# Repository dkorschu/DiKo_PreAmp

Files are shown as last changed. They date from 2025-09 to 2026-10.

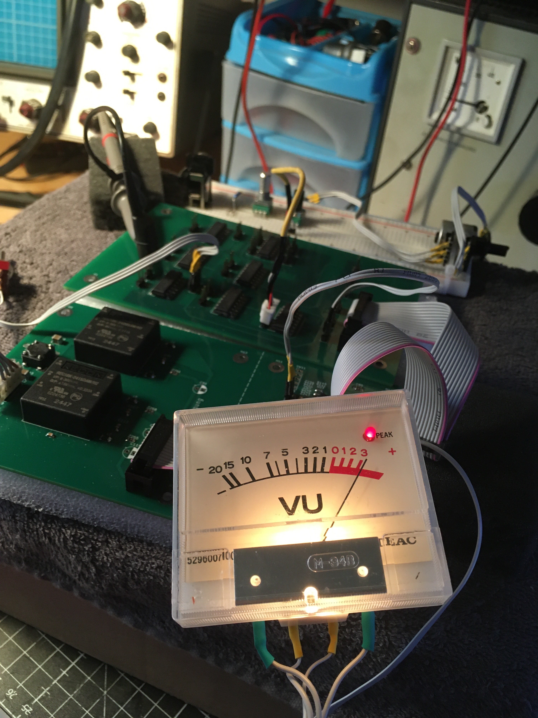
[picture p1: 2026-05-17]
Version 2/Pictures/Peak_Test.jpg

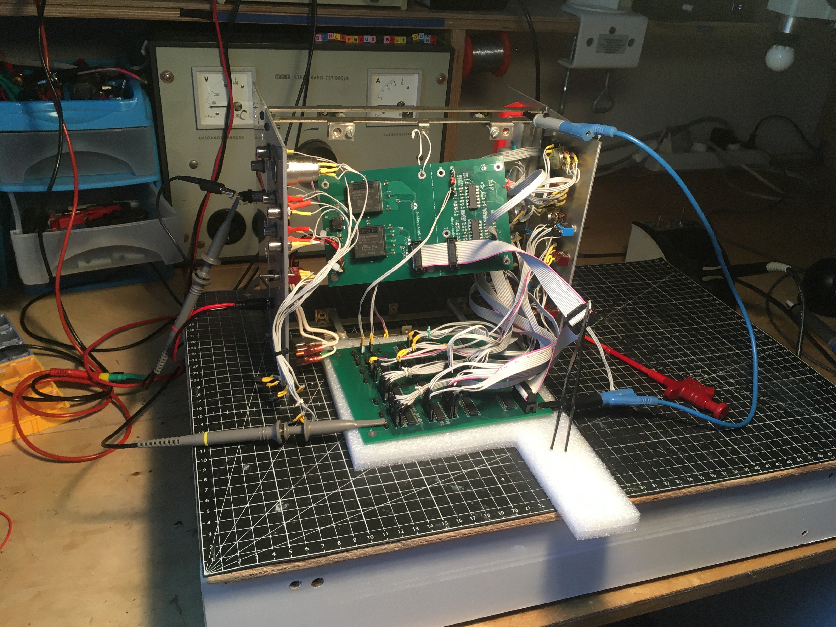
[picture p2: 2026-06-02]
Version 2/Pictures/Versuchsaufbau.jpg

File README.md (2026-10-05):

# $\text{-DIKO-}\sqrt{\text{REGGAE}}\text{-PREAMP-}$

[English version below](#english-version)

Dieses Repository zeigt die Entwicklung des DIKO ELEKTROTECHNIK Vorverstärkers, vom ersten Prototyp bis zum aktuellen Stand.

## Ordnerstruktur

- Blockschaltbilder
- Ältere Versionen
- KiCad Dateien
- Bilder
- Datenblätter
- 3D Druck

## Version 1

Version 1 entstand im Rahmen meiner Bachelorarbeit. Schaltpläne und Fertigungsdateien der Platinen wurden mit Altium Designer erstellt. Das Besondere an dieser Version: Die analoge Frequenzweiche lässt sich über Digitalpotentiometer einstellen.

**Hinweis: Version 1 ist fehlerhaft!**

## Version 2

Version 2 baut auf den Erkenntnissen aus Version 1 auf und bringt komplett neue Platinen mit. Die Digitalpotentiometer sind entfallen, da der Vorverstärker einfacher werden und der Fokus zunächst auf der analogen Schaltungstechnik liegen sollte. Zur Berechnung der Frequenzweiche wurden außerdem Jupyter Notebooks eingesetzt, die sehr gute Ergebnisse geliefert haben.

Bei den bisherigen Tests wurden schaltungstechnisch keine Fehler gefunden. Trotzdem gibt es zwei Schwachstellen:

- Das Platinenlayout ist nicht zufriedenstellend.
- Der Mikrofonvorverstärker verstärkt das Signal nicht ausreichend.

Aus diesen Gründen wird nun an Version 3 gearbeitet.

## Version 3

Version 3 teilt den Vorverstärker in einzelne Komponenten auf, die sich miteinander verbinden lassen.

2026_10_05 Den Anfang macht die Frequenzweiche, die sich auch eigenständig mit einem externen Mischpult nutzen lässt.

---

# English Version

This repository documents the development of the DIKO ELEKTROTECHNIK preamplifier, from the first prototype to the current state.

## Folder Structure

- Blockschaltbilder (block diagrams)
- Ältere Versionen (older versions)
- KiCad Dateien (KiCad files)
- Bilder (images)
- Datenblätter (datasheets)
- 3D Druck (3D printing)

## Version 1
Version 1 was developed as part of my bachelor's thesis. The schematics and PCB manufacturing files were created with Altium Designer. What makes this version special: the analog crossover can be adjusted using digital potentiometers.

**Note: Version 1 is faulty!**

## Version 2

Version 2 builds on the findings from Version 1 and comes with completely new PCBs. The digital potentiometers were removed to make the preamp simpler and to focus on the analog circuitry first. In addition, Jupyter Notebooks were used to calculate the crossover, with very good results.

So far, testing has not revealed any circuit errors. However, there are two weak points:

- The PCB layout is not satisfactory.
- The microphone preamp does not amplify the signal sufficiently.

For these reasons, work is now underway on Version 3.

## Version 3

Version 3 splits the preamp into individual components that can be connected to each other.

2026_10_05 The first step is the crossover, which can also be used on its own with an external mixing console.

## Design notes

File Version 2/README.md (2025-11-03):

# DiKo\_PreAmp

This repository contains all resources related to the design, development and documentation of an audio preamplifier that was created as part of a bachelor’s thesis. The preamplifier includes a crossover network whose transmission characteristics can be adjusted using digital potentiometers.

## Repository Structure

* **3D\_Print/**  

&nbsp;	Contains 3D print files for the PCB mounting bracket.

* **Altium/**  

&nbsp;	Altium Designer project of the preamplifier, including schematics and Gerber files.  
	Note: The current design contains electrical errors. These will be documented and fixed in an upcoming update.

* **Bachelor\_Thesis/**  

&nbsp;	Includes the bachelor’s thesis in which the preamplifier was developed.

* **Blockdiagram/**  

&nbsp;	Contains the block diagram of the preamplifier.

* **Pictures/**  

&nbsp;	Photos of the preamplifier prototype.

* **Software/**  

&nbsp;	Source code for both the microcontroller firmware and the desktop application used to control the digital potentiometers.
	The microcontroller was programmed using the Arduino IDE and the desktop application was developed in C# with Microsoft Visual Studio.

* **KiCad/**

&nbsp;	KiCad project of the preamplifier, including schematics and Gerber files.  

&nbsp;	Note: The current data set is incomplete and will be completed in an upcoming update.

* **Datasheed/**

	Contains data sheets and related reference information for the project components.

## Status

* Initial release of design files and documentation.
* Known circuit errors in the **Altium/** project (to be listed in detail soon).

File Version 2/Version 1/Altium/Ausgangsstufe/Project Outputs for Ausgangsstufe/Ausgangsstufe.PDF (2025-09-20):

Comment | Description | Designator | Footprint | LibRef | Quantity
OPA4134UA | SoundPlus(TM) High Performance Audio Operational Amplifier, 5 to 36 V, -55 to 125 degC, 14-pin SOIC (D14), Green (RoHS & no Sb/Br) | U22, U23, U24, U25, U26, U27, U28, U29, U30 | DIP14 IC Socket | SOIC OPA4134UA | 9
Schalter Buchsenleiste | Toggle Switch SPDT Through Hole | S1, S2, S3, S4 | Connector x3 | Schalter Buchsenleiste | 4
18k | 0805 Widerstand | R103 | 0805 | 0805 Widerstand | 1
100k | 0805 Widerstand | R93 | 0805 | 0805 Widerstand | 1
1k8 | 0805 Widerstand | R92, R97 | 0805 | 0805 Widerstand | 2
10k lin | 4mm Square Trimpot(R) Trimming Potentiometer, 5 KOhm, +/- 20%, 0.25 W, -55 to 125 degC, 3-Pin SMD, RoHS, Tape and Reel | R91 | SMD Trimmer 3314G | SMD Trimmer 3314G | 1
200k | 0805 Widerstand | R88, R99, R106 | 0805 | 0805 Widerstand | 3
50k lin | 4mm Square Trimpot(R) Trimming Potentiometer, 5 KOhm, +/- 20%, 0.25 W, -55 to 125 degC, 3-Pin SMD, RoHS, Tape and Reel | R82 | SMD Trimmer 3314G | SMD Trimmer 3314G | 1
3k9 | 0805 Widerstand | R79 | 0805 | 0805 Widerstand | 1
220 | 0805 Widerstand | R75 | 0805 | 0805 Widerstand | 1
1k | 0805 Widerstand | R49, R65, R81 | 0805 | 0805 Widerstand | 3
470R | 0805 Widerstand | R45, R47, R48, R50, R51, R59, R77, R87, R98 | 0805 | 0805 Widerstand | 9
22k log | Potentiometer | R44, R58, R73 | Connector x3 | Potentiometer Buchsenleiste | 3
4k7 | 0805 Widerstand | R41, R57, R67, R72, R76 | 0805 | 0805 Widerstand | 5
47k log/str | Potentiometer | R28, R29 | Connector x3 | Potentiometer Buchsenleiste | 2
5k | 0805 Widerstand | R24, R31 | 0805 | 0805 Widerstand | 2
10k | 0805 Widerstand | R17, R18, R19, R20, R21, R23, R40, R56, R66, R69, R70, R71, R74, R78, R84, R85, R86, R95, R96, R105 | 0805 | 0805 Widerstand | 20
47k lin | Potentiometer | R15, R16, R42, R43 | Connector x3 | Potentiometer Buchsenleiste | 4
220k | 0805 Widerstand | R13, R14, R30, R38, R39, R46, R52, R53, R54, R55, R60, R61, R62, R63, R64, R68, R80, R83, R89, R90, R94, R100, R101, R102, R104, R107 | 0805 | 0805 Widerstand | 26
6.8k | 0805 Widerstand | R7, R8, R10, R11, R32, R33, R34, R36 | 0805 | 0805 Widerstand | 8
470k log/str | Potentiometer | R5, R6 | Connector x3 | Potentiometer Buchsenleiste | 2
22k log/str | Potentiometer | R2, R3, R26, R27 | Connector x3 | Potentiometer Buchsenleiste | 4
22k | 0805 Widerstand | R1, R4, R9, R12, R22, R25, R35, R37 | 0805 | 0805 Widerstand | 8
BC817-40,215 | TRANS NPN 45V 0.5A SOT23 | Q2 | SOT23 Transistor | SOT23 BC817NPN | 1
BC807-40LT1G | General Purpose Transistor, PNP Silicon, 3-Pin SOT-23, Pb-Free, Tape and Reel | Q1 | SOT23 Transistor | SOT23 BC807 PNP | 1
VU Meter | CONN RCPT 4POS 0.1 GOLD PCB | J10 | Connector x4 | Connector x4 | 1
Connector x14 | 14 Position Header Connector Through Hole | J9 | Connector x14 | Connector x14 | 1
Connector x2 | Connector Header Through Hole 2 position 0.100 (2.54mm) | J1, J2, J3, J4, J5, J6, J7, J8, J11, J12, J13, J14 | Connector x2 | Connector x2 | 12
1N4148WS-7-F | Fast Switching Diode, 75 V, 0.3 A, -65 to 150 degC, 2-Pin SOD323, RoHS, Tape and Reel | D2, D3 | 1N4148 Diode | 1N4148 Diode | 2
WP710A10LGD | WP710A10LGD LED Thru-Hole PCB Green T-1 3mm Green Lens 2mA 568 nm 2mcd Round | Kingbright WP710A10LGD | D1 | Connector x2 | LED Buchsenleiste | 1
100n | 0805 Kondensator | C38, C39, C40, C41, C42, C43, C44, C45, C46, C47, C49, C50, C51, C52, C53, C54, C55, C56 | 0805 | 0805 Kondensator | 18
4.7u | 0805 Kondensator | C36 | 0805 | 0805 Kondensator | 1
1u | 0805 Kondensator | C25 | 0805 | 0805 Kondensator | 1
91n | 0805 Kondensator | C14 | 0805 | 0805 Kondensator | 1
30n | 0805 Kondensator | C9 | 0805 | 0805 Kondensator | 1
750p | 0805 Kondensator | C8 | 0805 | 0805 Kondensator | 1
6.8n | 0805 Kondensator | C6 | 0805 | 0805 Kondensator | 1
390n | 0805 Kondensator | C4 | 0805 | 0805 Kondensator | 1
2.2n | 0805 Kondensator | C3, C12 | 0805 | 0805 Kondensator | 2
10u | 0805 Kondensator | C2, C5, C7, C10, C11, C13, C15, C16, C17, C18, C19, C20, C21, C22, C23, C24, C26, C27, C28, C29, C30, C31, C32, C33, C34, C35, C37, C48, C57 | 0805 | 0805 Kondensator | 29
130n | 0805 Kondensator | C1 | 0805 | 0805 Kondensator | 1

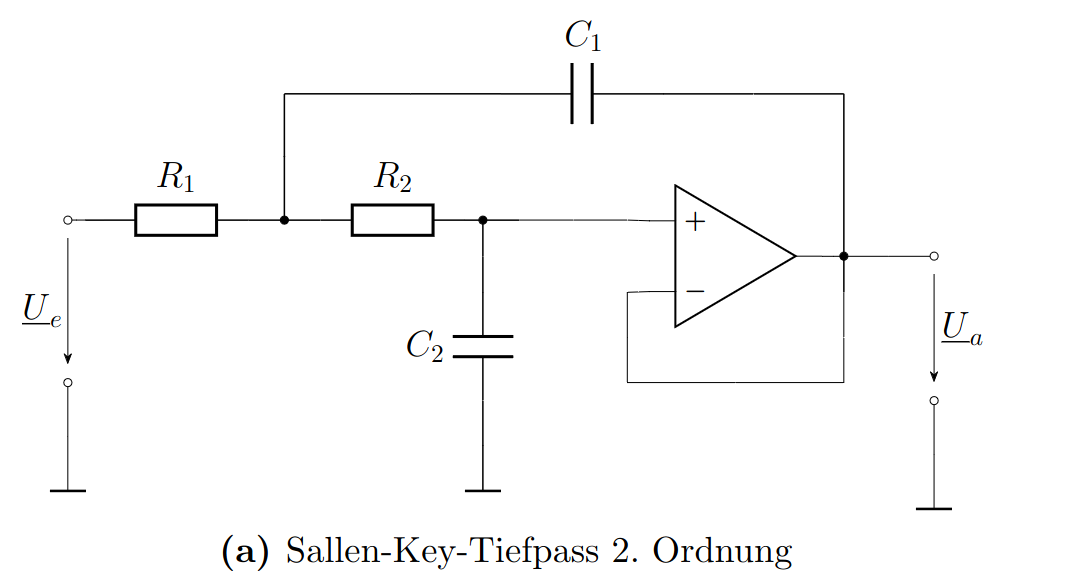
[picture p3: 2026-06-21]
Version 2/Notebook/img/Tiefpass.png

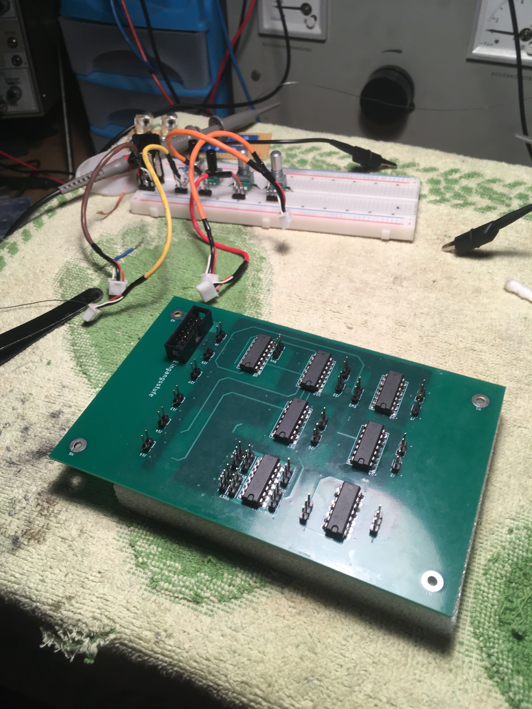
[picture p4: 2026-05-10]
Version 2/Pictures/Impression_Eingangsstufe_2.jpg

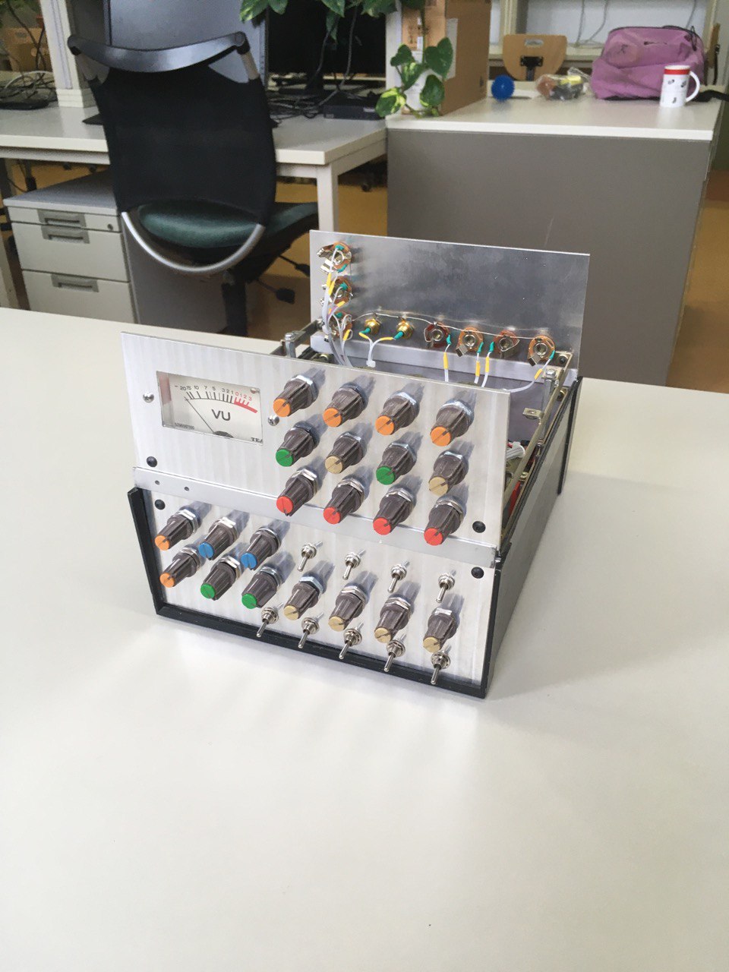
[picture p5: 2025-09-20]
Version 2/Pictures/Pre_amp_Front_alt.jpg

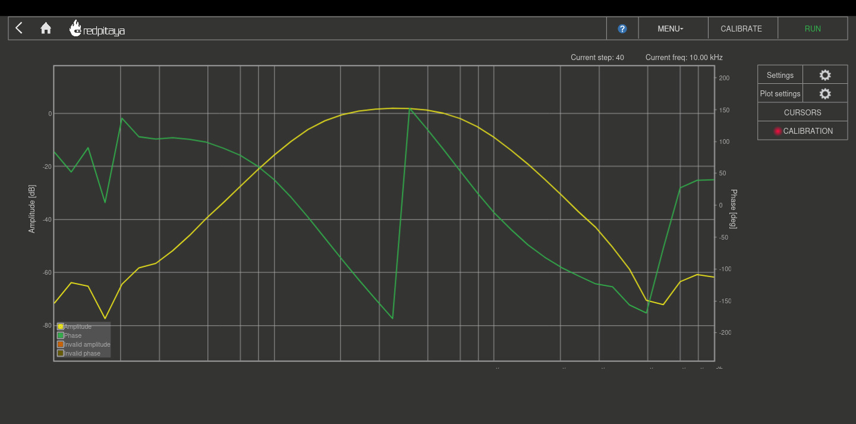
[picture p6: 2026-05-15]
Version 2/Pictures/Bass_Bandpass_Bode.jpg

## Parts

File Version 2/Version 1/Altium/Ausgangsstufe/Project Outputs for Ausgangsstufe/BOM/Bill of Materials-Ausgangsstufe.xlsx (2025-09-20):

Comment | Description | Designator | Footprint | LibRef | Quantity
OPA4134UA | SoundPlus(TM) High Performance Audio Operational Amplifier, 5 to 36 V, -55 to 125 degC, 14-pin SOIC (D14), Green (RoHS & no Sb/Br) | U22, U23, U24, U25, U26, U27, U28, U29, U30 | DIP14 IC Socket | SOIC OPA4134UA | 9
Schalter Buchsenleiste | Toggle Switch SPDT Through Hole | S7, S8, S9, S10 | Connector x3 | Schalter Buchsenleiste | 4
18k | 0805 Widerstand | R214 | 0805 | 0805 Widerstand | 1
100k | 0805 Widerstand | R205 | 0805 | 0805 Widerstand | 1
1k8 | 0805 Widerstand | R204, R208 | 0805 | 0805 Widerstand | 2
10k lin | 4 mm Square Trimpot(R) Trimming Potentiometer, 5 KOhm, +/- 20%, 0.25 W, -55 to 125 degC, 3-Pin SMD, RoHS, Tape and Reel | R202 | SMD Trimmer 3314G | SMD Trimmer 3314G | 1
200k | 0805 Widerstand | R199, R211, R218 | 0805 | 0805 Widerstand | 3
3k9 | 0805 Widerstand | R192 | 0805 | 0805 Widerstand | 1
50k lin | 4 mm Square Trimpot(R) Trimming Potentiometer, 5 KOhm, +/- 20%, 0.25 W, -55 to 125 degC, 3-Pin SMD, RoHS, Tape and Reel | R191 | SMD Trimmer 3314G | SMD Trimmer 3314G | 1
220 | 0805 Widerstand | R187 | 0805 | 0805 Widerstand | 1
1k | 0805 Widerstand | R161, R177, R194 | 0805 | 0805 Widerstand | 3
470R | 0805 Widerstand | R157, R159, R160, R162, R164, R172, R189, R198, R210 | 0805 | 0805 Widerstand | 9
22k log | Potentiometer | R156, R170, R185 | Connector x3 | Potentiometer Buchsenleiste | 3
4k7 | 0805 Widerstand | R153, R169, R179, R184, R188 | 0805 | 0805 Widerstand | 5
47k log/str | Potentiometer | R140, R141 | Connector x3 | Potentiometer Buchsenleiste | 2
5k | 0805 Widerstand | R136, R143 | 0805 | 0805 Widerstand | 2
47k lin | Potentiometer | R129, R130, R154, R155 | Connector x3 | Potentiometer Buchsenleiste | 4
220k | 0805 Widerstand | R126, R128, R142, R150, R151, R158, R163, R165, R166, R167, R171, R173, R174, R175, R176, R182, R193, R195, R200, R201, R206, R212, R213, R215, R216, R219 | 0805 | 0805 Widerstand | 26
10k | 0805 Widerstand | R119, R120, R131, R132, R133, R135, R152, R168, R178, R180, R181, R183, R186, R190, R196, R197, R203, R207, R209, R217 | 0805 | 0805 Widerstand | 20
6.8k | 0805 Widerstand | R116, R117, R121, R123, R144, R145, R146, R147 | 0805 | 0805 Widerstand | 8
470k log/str | Potentiometer | R114, R115 | Connector x3 | Potentiometer Buchsenleiste | 2
22k log/str | Potentiometer | R110, R111, R138, R139 | Connector x3 | Potentiometer Buchsenleiste | 4
22k | 0805 Widerstand | R109, R112, R118, R124, R134, R137, R148, R149 | 0805 | 0805 Widerstand | 8
BC817-40,215 | TRANS NPN 45V 0.5A SOT23 | Q2 | SOT23 Transistor | SOT23 BC817 NPN | 1
BC807-40LT1G | General Purpose Transistor, PNP Silicon, 3-Pin SOT-23, Pb-Free, Tape and Reel | Q1 | SOT23 Transistor | SOT23 BC807 PNP | 1
VU Meter | CONN RCPT 4POS 0.1 GOLD PCB | J15 | Connector x4 | Connector x4 | 1
Connector x14 | 14 Position Header Connector Through Hole | J14 | Connector x14 | Connector x14 | 1
Connector x2 | Connector Header Through Hole 2 position 0.100 (2.54mm) | J6, J7, J8, J9, J10, J11, J12, J13, J16, J17, J18, J19 | Connector x2 | Connector x2 | 12
1N4148WS-7-F | Fast Switching Diode, 75 V, 0.3 A, -65 to 150 degC, 2-Pin SOD323, RoHS, Tape and Reel | D2, D3 | 1N4148 Diode | 1N4148 Diode | 2
WP710A10LGD | WP710A10LGD LED Thru-Hole PCB Green T-1 3mm Green Lens 2 mA 568 nm 2 mcd Round | Kingbright WP710A10LGD | D1 | Connector x2 | LED Buchsenleiste | 1
100n | 0805 Kondensator | C153, C154, C155, C156, C157, C158, C159, C160, C161, C162, C165, C166, C167, C168, C169, C170, C171, C172 | 0805 | 0805 Kondensator | 18
4.7u | 0805 Kondensator | C151 | 0805 | 0805 Kondensator | 1
1u | 0805 Kondensator | C142 | 0805 | 0805 Kondensator | 1
91n | 0805 Kondensator | C131 | 0805 | 0805 Kondensator | 1
30n | 0805 Kondensator | C127 | 0805 | 0805 Kondensator | 1
750p | 0805 Kondensator | C126 | 0805 | 0805 Kondensator | 1
6.8n | 0805 Kondensator | C123 | 0805 | 0805 Kondensator | 1
390n | 0805 Kondensator | C121 | 0805 | 0805 Kondensator | 1
10u | 0805 Kondensator | C120, C122, C124, C125, C128, C130, C132, C133, C134, C135, C136, C137, C138, C139, C140, C141, C143, C144, C145, C146, C147, C148, C149, C150, C152, C163, C164, C173, C174 | 0805 | 0805 Kondensator | 29
2.2n | 0805 Kondensator | C118, C129 | 0805 | 0805 Kondensator | 2
130n | 0805 Kondensator | C117 | 0805 | 0805 Kondensator | 1

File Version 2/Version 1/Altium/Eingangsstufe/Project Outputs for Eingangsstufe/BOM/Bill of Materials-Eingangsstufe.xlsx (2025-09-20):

Comment | Description | Designator | Footprint | LibRef | Quantity
10u | 0805 Kondensator | C1, C2, C3, C5, C10, C13, C14, C15, C16, C17, C18, C20, C21, C22, C23 | 0805 | 0805 Kondensator | 15
330p | 0805 Kondensator | C4, C12 | 0805 | 0805 Kondensator | 2
15p | 0805 Kondensator | C6, C9 | 0805 | 0805 Kondensator | 2
150n | 0805 Kondensator | C7 | 0805 | 0805 Kondensator | 1
470n | 0805 Kondensator | C8 | 0805 | 0805 Kondensator | 1
33u | 0805 Kondensator | C11 | 0805 | 0805 Kondensator | 1
100n | 0805 Kondensator | C19, C28, C29, C30, C31, C32, C33, C34, C35, C36, C119 | 0805 | 0805 Kondensator | 11
470p | 0805 Kondensator | C24 | 0805 | 0805 Kondensator | 1
3n | 0805 Kondensator | C25, C26 | 0805 | 0805 Kondensator | 2
20n | 0805 Kondensator | C27 | 0805 | 0805 Kondensator | 1
Phono_In | Connector Header Through Hole 3 position 0.100 (2.54mm) | J1 | Connector x3 | Connector x3 | 1
Connector x14 | 14 Position Header Connector Through Hole | J2 | Connector x14 | Connector x14 | 1
Line_In | Connector Header Through Hole 3 position 0.100 (2.54mm) | J3 | Connector x3 | Connector x3 | 1
XLR_In | Connector Header Through Hole 3 position 0.100 (2.54mm) | J4 | Connector x3 | Connector x3 | 1
10k | 0805 Widerstand | R1, R2, R14, R17, R18, R25, R28, R29, R30 | 0805 | 0805 Widerstand | 9
4k7 | 0805 Widerstand | R3 | 0805 | 0805 Widerstand | 1
220k | 0805 Widerstand | R4, R6, R8, R10, R16, R19, R20, R22, R23, R24, R26, R27, R32, R41, R42, R43, R44 | 0805 | 0805 Widerstand | 17
47k | 0805 Widerstand | R5, R15, R39, R40 | 0805 | 0805 Widerstand | 4
22k | 0805 Widerstand | R7, R9, R34, R35, R37, R38 | 0805 | 0805 Widerstand | 6
680 | 0805 Widerstand | R11 | 0805 | 0805 Widerstand | 1
1k | 0805 Widerstand | R12 | 0805 | 0805 Widerstand | 1
1k2 | 0805 Widerstand | R13 | 0805 | 0805 Widerstand | 1
47k lin | Potentiometer | R21, R45, R46 | Connector x3 | Potentiometer Buchsenleiste | 3
5k | 0805 Widerstand | R31, R33 | 0805 | 0805 Widerstand | 2
10k lin | Potentiometer | R36 | Connector x3 | Potentiometer Buchsenleiste | 1
220k log | Potentiometer | R47, R48, R49, R50 | Connector x3 | Potentiometer Buchsenleiste | 4
6.8k | 0805 Widerstand | R51, R107, R108, R113 | 0805 | 0805 Widerstand | 4
Phono/Line Schalter | Toggle Switch SPDT Through Hole | S1 | Connector x3 | Schalter Buchsenleiste | 1
Schalter Buchsenleiste | Toggle Switch SPDT Through Hole | S6 | Connector x3 | Schalter Buchsenleiste | 1
OPA4134UA | SoundPlus(TM) High Performance Audio Operational Amplifier, 5 to 36 V, -55 to 125 degC, 14-pin SOIC (D14), Green (RoHS & no Sb/Br) | U1, U2, U4, U5 | DIP14 IC Socket | SOIC OPA4134UA | 4
INA128U | Precision, Low Power Instrumentation Amplifier, -40 to 85 degC, 8-pin SOIC (D8), Green (RoHS & no Sb/Br) | U3 | INA 128 | INA 128 | 1

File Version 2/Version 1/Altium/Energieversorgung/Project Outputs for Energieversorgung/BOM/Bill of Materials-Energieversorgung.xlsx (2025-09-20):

Comment | Description | Designator | Footprint | LibRef | Quantity
330n | 0805 Kondensator | C175, C181 | 0805 | 0805 Kondensator | 2
100n | 0805 Kondensator | C176, C182, C185 | 0805 | 0805 Kondensator | 3
470uF/40V | Aluminum Electrolytic Capacitors (Radial Lead Type) | C177, C178 | ELKO 12.5mm | Elko 12.5mm | 2
3300u | Aluminum Electrolytic Capacitors (Radial Lead Type) | C179, C180, C183, C184 | Elko 16mm | Elko 16mm | 4
1u | 0805 Kondensator | C186 | 0805 | 0805 Kondensator | 1
2u | 0805 Kondensator | C187 | 0805 | 0805 Kondensator | 1
1N4001 Diode | Standard Recovery Rectifier, 2-Pin Axial_Lead, Pb-Free, Bulk Bag | D4, D5, D6, D7 | 1N4001 Diode | 1N4001 Diode | 4
Connector x2 | Connector Header Through Hole 2 position 0.100 (2.54mm) | J20, J21 | Connector x2 | Connector x2 | 2
Connector x14 | 14 Position Header Connector Through Hole | J22, J23, J24 | Connector x14 | Connector x14 | 3
RTB14024F | RELAY GEN PURPOSE SPDT 12A 24V | K1 | Relay 24V | Relay 24V | 1
2K | 0805 Widerstand | R220 | THT Widerstand 0.25W | THT Widerstand 0.25W | 1
10R/10W | 0805 Widerstand | R221, R222, R223 | Widerstand THT 10W | Widerstand THT 10W | 3
G23AP | SWITCH TOGGLE DPDT 0.4VA 28V | SW1 | Connector x4 | Schalter 2x3 | 1
7806 | Voltage Regulator, 3-Pin TO-220 | U31 | TO220 Spannungsregler 78xx | TO 220 Spannungsregler 78xx | 1
7818 | Voltage Regulator, 3-Pin TO-220 | U32 | TO220 Spannungsregler 78xx | TO 220 Spannungsregler 78xx | 1
7918 | Voltage Regulator, 3-Pin TO-220 | U33 | TO220 Spannungsregler 79xx | TO 220 Spannungsregler 79xx | 1

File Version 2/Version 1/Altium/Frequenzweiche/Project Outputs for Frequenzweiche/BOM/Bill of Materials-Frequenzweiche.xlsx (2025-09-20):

Comment | Description | Designator | Footprint | LibRef | Quantity
10u | 0805 Kondensator | C1, C2, C3, C4, C39, C44, C52, C57, C64, C65, C71, C78, C83, C88, C90 | 0805 | 0805 Kondensator | 15
22n | 0805 Kondensator | C37, C38, C42, C43, C45, C46, C47, C48, C50, C51, C55, C56, C58, C59, C60, C61, C62, C63, C69, C70, C72, C73, C74, C75, C76, C77, C81, C82, C84, C85, C86, C87 | 0805 | 0805 Kondensator | 32
100n | 0805 Kondensator | C92, C93, C94, C95, C96, C97, C98, C99, C100, C101, C102, C103, C104, C105, C106, C107, C108, C109, C110, C111, C112, C113, C114, C115, C116 | 0805 | 0805 Kondensator | 25
Connector x14 | 14 Position Header Connector Through Hole | J5 | Connector x14 | Connector x14 | 1
A000005 | ARDUINO NANO ATMEGA328 EVAL BRD | MD1 | Arduino Nano | Arduino Nano | 1
220k | 0805 Widerstand | R1, R2, R3, R4, R54, R55, R60, R61, R69, R70, R73, R80, R81, R84, R95 | 0805 | 0805 Widerstand | 15
4k7 | 0805 Widerstand | R52, R62, R75, R88 | 0805 | 0805 Widerstand | 4
10k | 0805 Widerstand | R53, R63, R64, R65, R66, R68, R76, R77, R78, R79, R83, R89, R90, R91, R92, R94 | 0805 | 0805 Widerstand | 16
20k log | Potentiometer | R56 | Connector x3 | Potentiometer Buchsenleiste | 1
2k2 | 0805 Widerstand | R58, R71, R86, R97 | 0805 | 0805 Widerstand | 4
5k | 0805 Widerstand | R59, R74, R87, R102 | 0805 | 0805 Widerstand | 4
50k log | Potentiometer | R67, R82, R93 | Connector x3 | Potentiometer Buchsenleiste | 3
Schalter Buchsenleiste | Toggle Switch SPDT Through Hole | S2, S3, S4, S5 | Connector x3 | Schalter Buchsenleiste | 4
Test_Pin | Connector Header Through Hole 2 position 0.100 (2.54mm) | TP1, TP2, TP3, TP4, TP5, TP6, TP7, TP8, TP9, TP10, TP11, TP12 | Test_Pin | Test_Pin | 12
OPA4134UA | SoundPlus(TM) High Performance Audio Operational Amplifier, 5 to 36 V, -55 to 125 degC, 14-pin SOIC (D14), Green (RoHS & no Sb/Br) | U6, U7, U8, U9, U10, U11, U12, U13 | DIP14 IC Socket | SOIC OPA4134UA | 8
MCP4361-103E/ST | 7/8-Bit Quad SPI Digital POT with Non-Volatile Memory, 20-Pin TSSOP, Extended Temperature | U14, U15, U16, U17, U18, U19, U20, U21 | MCP 4361 | MCP 4361 | 8

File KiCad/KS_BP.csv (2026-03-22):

Reference | Qty | Value | Exclude from Board | Footprint | Datasheet | Sim.Pins
C1 | 1 | 2n2 |  | Capacitor_SMD:C_0805_2012Metric_Pad1.18x1.45mm_HandSolder | ~
C2,C89,C100,C112,C119 | 5 | 10n |  | Capacitor_SMD:C_0805_2012Metric_Pad1.18x1.45mm_HandSolder | ~
C3,C4,C85 | 3 | 10n |  | Capacitor_SMD:C_1210_3225Metric_Pad1.33x2.70mm_HandSolder | ~
C5,C6,C7,C8,C10,C11,C13,C14,C16,C17,C18,C19,C20,C21,C23,C24,C26,C27,C28,C29,C30,C31,C34,C35,C38,C39,C40,C41,C42,C43,C45,C46 | 32 | 130n |  | Capacitor_SMD:C_0805_2012Metric_Pad1.18x1.45mm_HandSolder | ~
C9 | 1 | 47u |  | Capacitor_SMD:C_0805_2012Metric_Pad1.18x1.45mm_HandSolder | ~
C12,C22,C32,C33,C44,C48,C84,C103,C110,C121 | 10 | 470p |  | Capacitor_SMD:C_0805_2012Metric_Pad1.18x1.45mm_HandSolder | ~
C15,C25,C36,C37,C47,C49 | 6 | 3n |  | Capacitor_SMD:C_0805_2012Metric_Pad1.18x1.45mm_HandSolder | ~
C50,C51 | 2 | 6n8 |  | Capacitor_SMD:C_0805_2012Metric_Pad1.18x1.45mm_HandSolder | ~
C52,C53,C54,C55,C56,C57,C58,C59,C60,C61,C62,C63,C64,C65,C66,C67,C68,C69,C70,C71,C72,C73,C74,C75,C76,C77,C78,C79,C80,C81,C82,C83,C87,C88,C90,C92,C93,C94,C95,C96,C97,C98,C99,C104,C105,C106,C107,C108,C109,C113,C117 | 51 | 100n |  | Capacitor_SMD:C_0805_2012Metric_Pad1.18x1.45mm_HandSolder | ~
C86,C102,C111,C120 | 4 | 1n |  | Capacitor_SMD:C_0805_2012Metric_Pad1.18x1.45mm_HandSolder | ~
C91,C114,C118 | 3 | 10u |  | Capacitor_THT:CP_Radial_D5.0mm_P2.50mm | ~
C101 | 1 | 4u7 |  | Capacitor_SMD:C_0805_2012Metric_Pad1.18x1.45mm_HandSolder | ~
C115,C116 | 2 | 10u |  | Capacitor_SMD:C_1210_3225Metric_Pad1.33x2.70mm_HandSolder | ~
D1,D2,D4 | 3 | D |  | Diode_SMD:D_0805_2012Metric_Pad1.15x1.40mm_HandSolder | ~ | 1=K 2=A
D3 | 1 | LED |  | LED_THT:LED_D3.0mm | ~ | 1=K 2=A
H1,H2,H5,H6,H7,H8,H9,H10,H11,H13,H14,H15,H16 | 13 | MountingHole |  | MountingHole:MountingHole_3.2mm_M3_Pad | ~
H3,H4,H12 | 3 | MountingHole_Pad |  | MountingHole:MountingHole_3.2mm_M3_Pad | ~
J1 | 1 | Bass_Out |  | Connector_PinSocket_2.54mm_LongPads:PinSocket_1x02_P2.54mm_Vertical_LongPads | ~
J2 | 1 | R_Phono_In |  | Connector_PinHeader_2.54mm_LongPads:PinHeader_1x02_P2.54mm_Vertical_LongPads | ~
J3 | 1 | L_Phono_In |  | Connector_PinHeader_2.54mm_LongPads:PinHeader_1x02_P2.54mm_Vertical_LongPads | ~
J4 | 1 | Phono/Line_Out |  | Connector_PinSocket_2.54mm_LongPads:PinSocket_1x02_P2.54mm_Vertical_LongPads | ~
J5 | 1 | Phono/Line_In |  | Connector_PinHeader_2.54mm_LongPads:PinHeader_1x02_P2.54mm_Vertical_LongPads | ~
J6 | 1 | Kick_Out |  | Connector_PinSocket_2.54mm_LongPads:PinSocket_1x02_P2.54mm_Vertical_LongPads | ~
J7 | 1 | R_Line_In |  | Connector_PinHeader_2.54mm_LongPads:PinHeader_1x02_P2.54mm_Vertical_LongPads | ~
J8 | 1 | L_Line_In |  | Connector_PinHeader_2.54mm_LongPads:PinHeader_1x02_P2.54mm_Vertical_LongPads | ~
J9 | 1 | Mic_In |  | Connector_PinHeader_2.54mm_LongPads:PinHeader_1x03_P2.54mm_Vertical_LongPads | ~
J10 | 1 | Mid_Out |  | Connector_PinSocket_2.54mm_LongPads:PinSocket_1x02_P2.54mm_Vertical_LongPads | ~
J11 | 1 | High_Out |  | Connector_PinSocket_2.54mm_LongPads:PinSocket_1x02_P2.54mm_Vertical_LongPads | ~
J12,J14,J16,J23,J27 | 5 | Mic_Effekt_Out |  | Connector_PinSocket_2.54mm_LongPads:PinSocket_1x02_P2.54mm_Vertical_LongPads | ~
J13,J15,J24 | 3 | Mic_Effekt_In |  | Connector_PinHeader_2.54mm_LongPads:PinHeader_1x02_P2.54mm_Vertical_LongPads | ~
J17 | 1 | AUX_RET_1 |  | Connector_PinHeader_2.54mm_LongPads:PinHeader_1x02_P2.54mm_Vertical_LongPads | ~
J18 | 1 | AUX_Send_1 |  | Connector_PinSocket_2.54mm_LongPads:PinSocket_1x02_P2.54mm_Vertical_LongPads | ~
J19 | 1 | Line_Out_L |  | Connector_PinSocket_2.54mm_LongPads:PinSocket_1x02_P2.54mm_Vertical_LongPads | ~
J20 | 1 | Effekt_In |  | Connector_PinHeader_2.54mm_LongPads:PinHeader_1x02_P2.54mm_Vertical_LongPads | ~
J21 | 1 | Line_Out_R |  | Connector_PinSocket_2.54mm_LongPads:PinSocket_1x02_P2.54mm_Vertical_LongPads | ~
J22 | 1 | AUX_RET_2 |  | Connector_PinHeader_2.54mm_LongPads:PinHeader_1x02_P2.54mm_Vertical_LongPads | ~
J25 | 1 | AUX_Send_3 |  | Connector_PinSocket_2.54mm_LongPads:PinSocket_1x02_P2.54mm_Vertical_LongPads | ~
J26 | 1 | AUX_Send_2 |  | Connector_PinSocket_2.54mm_LongPads:PinSocket_1x02_P2.54mm_Vertical_LongPads | ~
J28 | 1 | AUX_RET_3 |  | Connector_PinHeader_2.54mm_LongPads:PinHeader_1x02_P2.54mm_Vertical_LongPads | ~
J29,J32 | 2 | Pegel_Out |  | Connector_PinSocket_2.54mm_LongPads:PinSocket_1x02_P2.54mm_Vertical_LongPads | ~
J30,J31,J40,J41 | 4 | Conn_02x07_Odd_Even |  | Connector_PinHeader_2.54mm:PinHeader_2x07_P2.54mm_Vertical | ~
J33,J35,J36,J42 | 4 | Pegel_In |  | Connector_PinHeader_2.54mm_LongPads:PinHeader_1x02_P2.54mm_Vertical_LongPads | ~
J34 | 1 | VU_Meter_Out |  | Connector_PinSocket_2.54mm_LongPads:PinSocket_1x04_P2.54mm_Vertical_LongPdas | ~
J37 | 1 | LED_Out |  | Connector_PinSocket_2.54mm_LongPads:PinSocket_1x02_P2.54mm_Vertical_LongPads | ~
J38 | 1 | LED_In |  | Connector_PinHeader_2.54mm_LongPads:PinHeader_1x02_P2.54mm_Vertical_LongPads | ~
J39 | 1 | VCC_IN |  | Connector_PinHeader_2.54mm_LongPads:PinHeader_1x02_P2.54mm_Vertical_LongPads | ~
J43 | 1 | VCC_OUT |  | Connector_PinHeader_2.54mm_LongPads:PinHeader_1x02_P2.54mm_Vertical_LongPads | ~
L1,L2,L3,L5 | 4 | Dämpfungsperle, 220 Ohm @ 100MHz, 0.5A |  | Inductor_SMD:L_1206_3216Metric | ~
L4 | 1 | ~ |  | WE-SL575:WE-SL575
R1,R24,R26,R48,R78,R114,R129,R131 | 8 | 4k7 |  | Resistor_SMD:R_0805_2012Metric_Pad1.20x1.40mm_HandSolder | ~
R2,R7,R9,R16,R21,R25,R27,R30,R33,R44,R45,R49,R52,R53,R54,R57,R62,R63,R66,R67,R72,R75,R79,R80,R83,R89,R90,R92,R98,R102,R103,R104,R107,R108,R109,R111,R112,R115,R116,R117,R118,R120,R121,R124,R125,R126,R130,R132,R134,R135,R140,R147,R148,R152,R153,R154,R155,R156,R157 | 59 | 10k |  | Resistor_SMD:R_0805_2012Metric_Pad1.20x1.40mm_HandSolder | ~
R3 | 1 | 36k |  | Resistor_SMD:R_0805_2012Metric_Pad1.20x1.40mm_HandSolder | ~
R4 | 1 | 390k |  | Resistor_SMD:R_0805_2012Metric_Pad1.20x1.40mm_HandSolder | ~
R5,R6,R10,R11,R22,R23,R28,R29,R34,R35,R46,R47,R50,R51,R59,R60,R73,R74,R76,R77,R81,R82,R86,R87,R99,R100,R105,R106 | 28 | 6k8 |  | Resistor_SMD:R_0805_2012Metric_Pad1.20x1.40mm_HandSolder | ~
R8,R12,R17,R18,R19,R20,R31,R37,R40,R41,R42,R43,R55,R58,R64,R65,R68,R69,R70,R71,R84,R91,R93,R94,R95,R96,R97,R101 | 28 | 22k |  | Resistor_SMD:R_0805_2012Metric_Pad1.20x1.40mm_HandSolder | ~
R13,R32,R38,R56,R85,R122,R136,R137 | 8 | 470R |  | Resistor_SMD:R_0805_2012Metric_Pad1.20x1.40mm_HandSolder | ~
R14,R15,R36,R39,R61,R88,R123,R138,R139,R145,R146,R149 | 12 | 1k |  | Resistor_SMD:R_0805_2012Metric_Pad1.20x1.40mm_HandSolder | ~
R110,R113,R119,R127,R128,R133 | 6 | 5k |  | Resistor_SMD:R_0805_2012Metric_Pad1.20x1.40mm_HandSolder | ~
R141 | 1 | 20k |  | Resistor_SMD:R_0805_2012Metric_Pad1.20x1.40mm_HandSolder | ~
R142 | 1 | 80k |  | Resistor_SMD:R_0805_2012Metric_Pad1.20x1.40mm_HandSolder | ~
R143,R144 | 2 | 1k8 |  | Resistor_SMD:R_0805_2012Metric_Pad1.20x1.40mm_HandSolder | ~
R150 | 1 | 12k |  | Resistor_SMD:R_0805_2012Metric_Pad1.20x1.40mm_HandSolder | ~
R151 | 1 | 3k |  | Resistor_SMD:R_0805_2012Metric_Pad1.20x1.40mm_HandSolder | ~
RV1,RV4,RV5,RV8,RV14,RV20,RV21,RV22 | 8 | 50k log |  | Connector_PinSocket_2.54mm_LongPads:PinSocket_1x03_P2.54mm_Vertical_LongPads | ~
RV2,RV10,RV17 | 3 | 220k log |  | Connector_PinSocket_2.54mm_LongPads:PinSocket_2x03_P2.54mm_Vertical_LongPads_Mirrored | ~
RV3,RV7,RV12,RV13,RV16,RV18 | 6 | 47k lin |  | Connector_PinSocket_2.54mm_LongPads:PinSocket_1x03_P2.54mm_Vertical_LongPads | ~
RV6,RV11,RV15,RV19 | 4 | 220k log |  | Connector_PinSocket_2.54mm_LongPads:PinSocket_2x03_P2.54mm_Vertical_LongPads | ~
RV9 | 1 | 10k lin |  | Connector_PinSocket_2.54mm_LongPads:PinSocket_1x03_P2.54mm_Vertical_LongPads | ~
SW1,SW3,SW4,SW5,SW6,SW7,SW8,SW9,SW10 | 9 | SW_SPDT |  | Connector_PinHeader_2.54mm_LongPads:PinHeader_1x02_P2.54mm_Vertical_LongPads | ~
SW2 | 1 | SW_SPDT |  | Connector_PinHeader_2.54mm_LongPads:PinHeader_1x03_P2.54mm_Vertical_LongPads | ~
SW11 | 1 | SW_Rotary_1x4 |  | Connector_PinHeader_2.54mm_LongPads:PinHeader_1x05_P2.54mm_Vertical_LongPads | ~
SW12 | 1 | SW_DPST |  | Connector_PinSocket_2.54mm_LongPads:PinSocket_1x04_P2.54mm_Vertical_LongPdas | ~
U1,U2,U3,U4,U5,U6,U7,U8,U9,U10,U11,U12,U13,U14,U15,U16,U17,U18,U19,U20,U21,U22,U23,U24 | 24 | TL074 |  | Package_DIP:DIP-14_W7.62mm_Socket_LongPads | http://www.ti.com/lit/ds/symlink/tl071.pdf
U8,U11,U17,U19 | 4 | TL074 |  |  | http://www.ti.com/lit/ds/symlink/tl071.pdf
U25 | 1 | REC10K-2409 |  | REC10K-2409SAW_H2:CONV_REC10K-2409SAW_H2
U26 | 1 | REC10K-2415 |  | REC10K-2415DAW_H2:CONV_REC10K-2415DAW_H2
Z1,Z2,Z3,Z4,Z5,Z6,Z7,Z8,Z9,Z10,Z11,Z12,Z13,Z14,Z15,Z16,Z17,Z18,Z19,Z20,Z21,Z22,Z23,Z24,Z25,Z26,Z27,Z28,Z29,Z30,Z31,Z32,Z33,Z34,Z35,Z36,Z37,Z38,Z39,Z40,Z41,Z42,Z43,Z44,Z45,Z46,Z47,Z48,Z49,Z50,Z51,Z52,Z53,Z54,Z55,Z56,Z57,Z58,Z59,Z60,Z61,Z62,Z63,Z64,Z65,Z66,Z67,Z68,Z69,Z70,Z71,Z72,Z73,Z74,Z75,Z76,Z77,Z78,Z79,Z80,Z81,Z82,Z83,Z84,Z85,Z86,Z87,Z88,Z89,Z90,Z91,Z92,Z93,Z94,Z95,Z96,Z97,Z98,Z99,Z100,Z101,Z102,Z103,Z104,Z105,Z106,Z107,Z108,Z109,Z110,Z111,Z112,Z113,Z114,Z115,Z116,Z117,Z118,Z119,Z120,Z121,Z122,Z123,Z124,Z125,Z126,Z127,Z128,Z129,Z130,Z131,Z132,Z133,Z134,Z135,Z136,Z137,Z138,Z139,Z140,Z141,Z142,Z143,Z144,Z145,Z146,Z147,Z148,Z149,Z150,Z151,Z152,Z153,Z154,Z155,Z156,Z157,Z158,Z159,Z160,Z161,Z162,Z163,Z164,Z165,Z166,Z167,Z168,Z169,Z170,Z171,Z172,Z173,Z174,Z175,Z176,Z177,Z178,Z179,Z180,Z181,Z182,Z183,Z184,Z185,Z186,Z187,Z188,Z189,Z190,Z191,Z192,Z193,Z194,Z195,Z196,Z197,Z198,Z199,Z200,Z201,Z202,Z203,Z204,Z205,Z206,Z207,Z208,Z209,Z210,Z211,Z212,Z213,Z214,Z215,Z216,Z217,Z218,Z219,Z220,Z221,Z222,Z223,Z224,Z225,Z226,Z227,Z228,Z229,Z230,Z231,Z232,Z233,Z234,Z235,Z236,Z237,Z238,Z239,Z240,Z241,Z242,Z243,Z244,Z245,Z246,Z247,Z248,Z249,Z250,Z251,Z252,Z253,Z254,Z255,Z256,Z257,Z258,Z259,Z260,Z261,Z262,Z263,Z264,Z265,Z266,Z267,Z268,Z269,Z270,Z271,Z272,Z273,Z274 | 274 | ~ |  | Resistor_SMD:R_0805_2012Metric_Pad1.20x1.40mm_HandSolder | ~

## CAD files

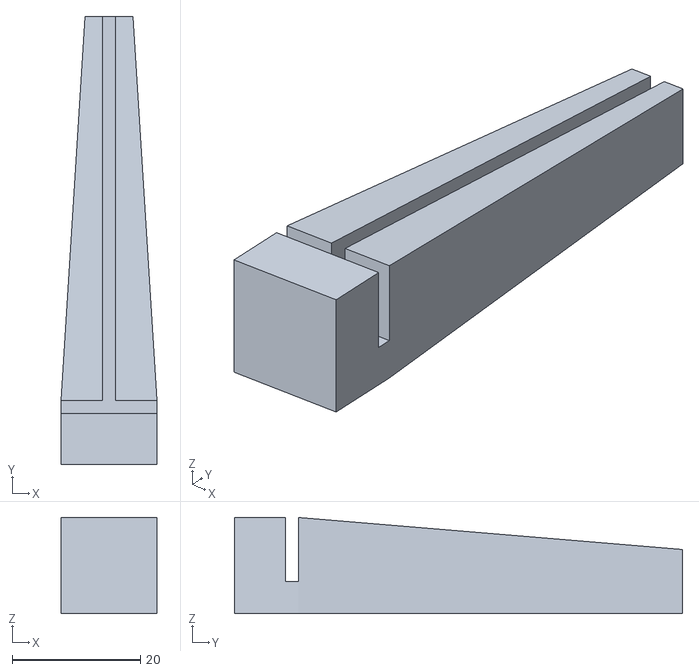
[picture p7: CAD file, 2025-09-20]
Version 2/Version 1/3D_Print/Platinen_Sockel_V1.stl
15.0 x 70.0 x 15.0

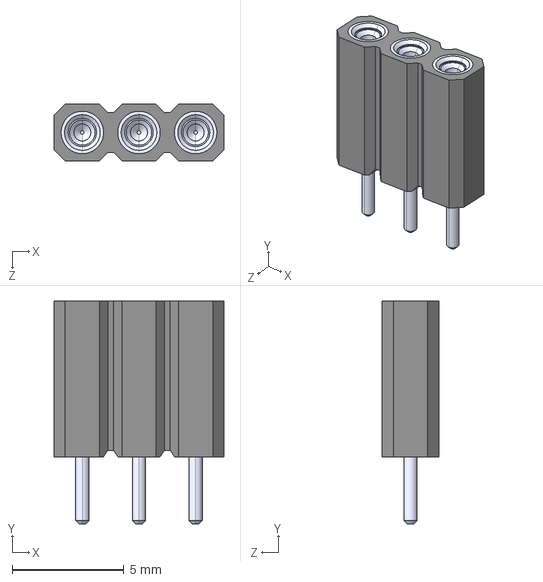
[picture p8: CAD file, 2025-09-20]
Version 2/Version 1/Altium/Bauteile/Downloads/Buchsenleiste x3/Buchsenleiste_x3.STEP
7.62 x 10.0 x 2.54 mm

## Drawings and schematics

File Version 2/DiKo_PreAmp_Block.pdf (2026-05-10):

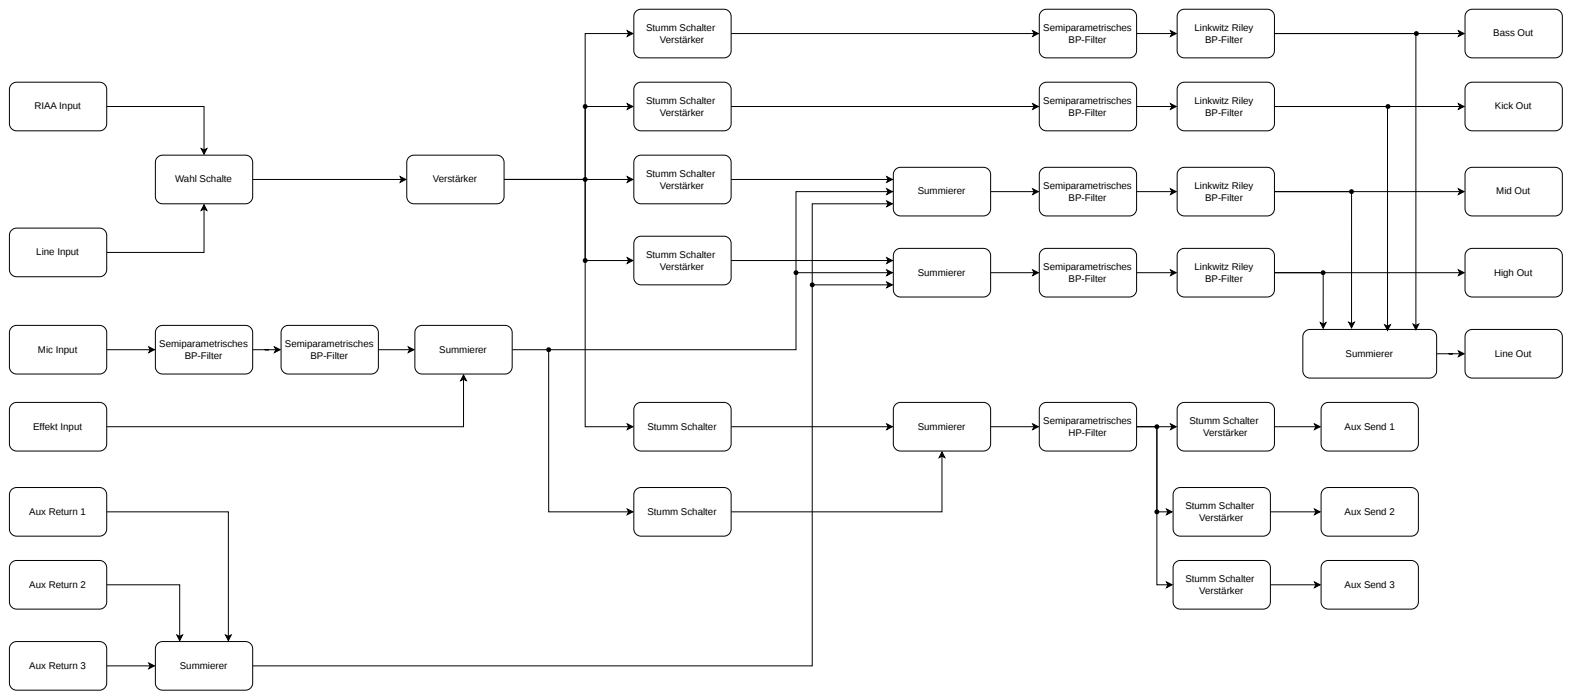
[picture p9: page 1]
RIAA Input; Line Input; Verstärker; Stumm Schalter Verstärker; Stumm Schalter; Semiparametrisches BP-Filter; Linkwitz Riley BP-Filter; Bass Out; Kick Out; Summierer; Semiparametrisches; BP-Filter; Mid Out; High Out; Mic Input; Effekt Input; Aux Send 1; Aux Send 2; Aux Send 3; Aux Return 1; Aux Return 2; Aux Return 3; Wahl Schalte; Line Out

HP-Filter Summierer

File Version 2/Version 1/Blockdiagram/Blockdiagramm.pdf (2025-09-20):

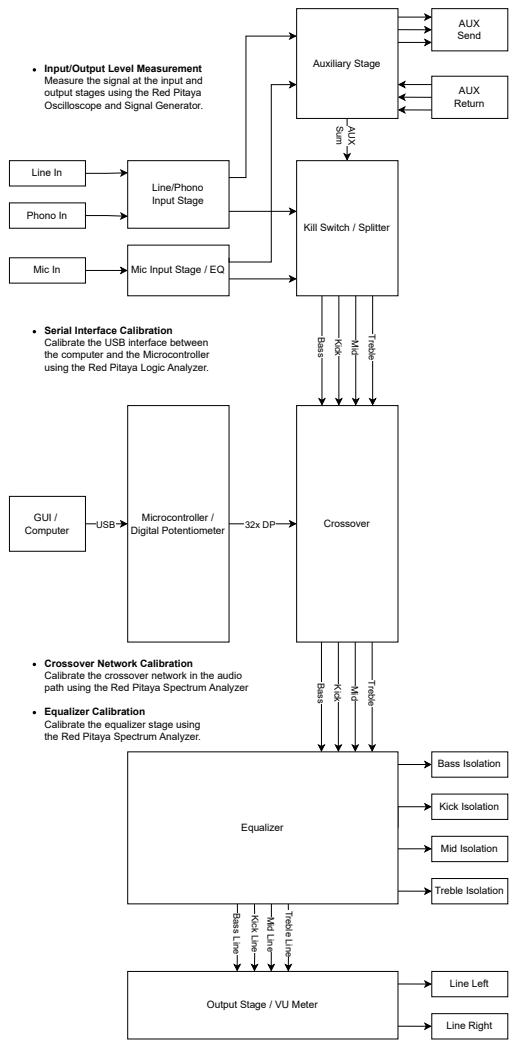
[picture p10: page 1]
Line/Phono Input Stage; Line In; Phono In; Mic In; Mic Input Stage / EQ; Crossover Microcontroller /; Digital Potentiometer; Treble; Equalizer; Bass Isolation; Kick Isolation; Mid Isolation; Treble Isolation; Bass Line; Kick Line; Mid Line; Treble Line; Line Left; Line Right; AUX Send; AUX Return; USB GUI / Computer; using the Red Pitaya Logic Analyzer.; Bass; Kick; Mid; reble

Input/Output Level Measurement
Measure the signal at the input and
output stages using the Red Pitaya
Oscilloscope and Signal Generator.

Auxiliary Stage Sum AUX

Kill Switch / Splitter

Serial Interface Calibration
Calibrate the USB interface between
the computer and the Microcontroller

Crossover Network Calibration
Calibrate the crossover network in the audio
path using the Red Pitaya Spectrum Analyzer

Equalizer Calibration
Calibrate the equalizer stage using
the Red Pitaya Spectrum Analyzer.

Output Stage / VU Meter

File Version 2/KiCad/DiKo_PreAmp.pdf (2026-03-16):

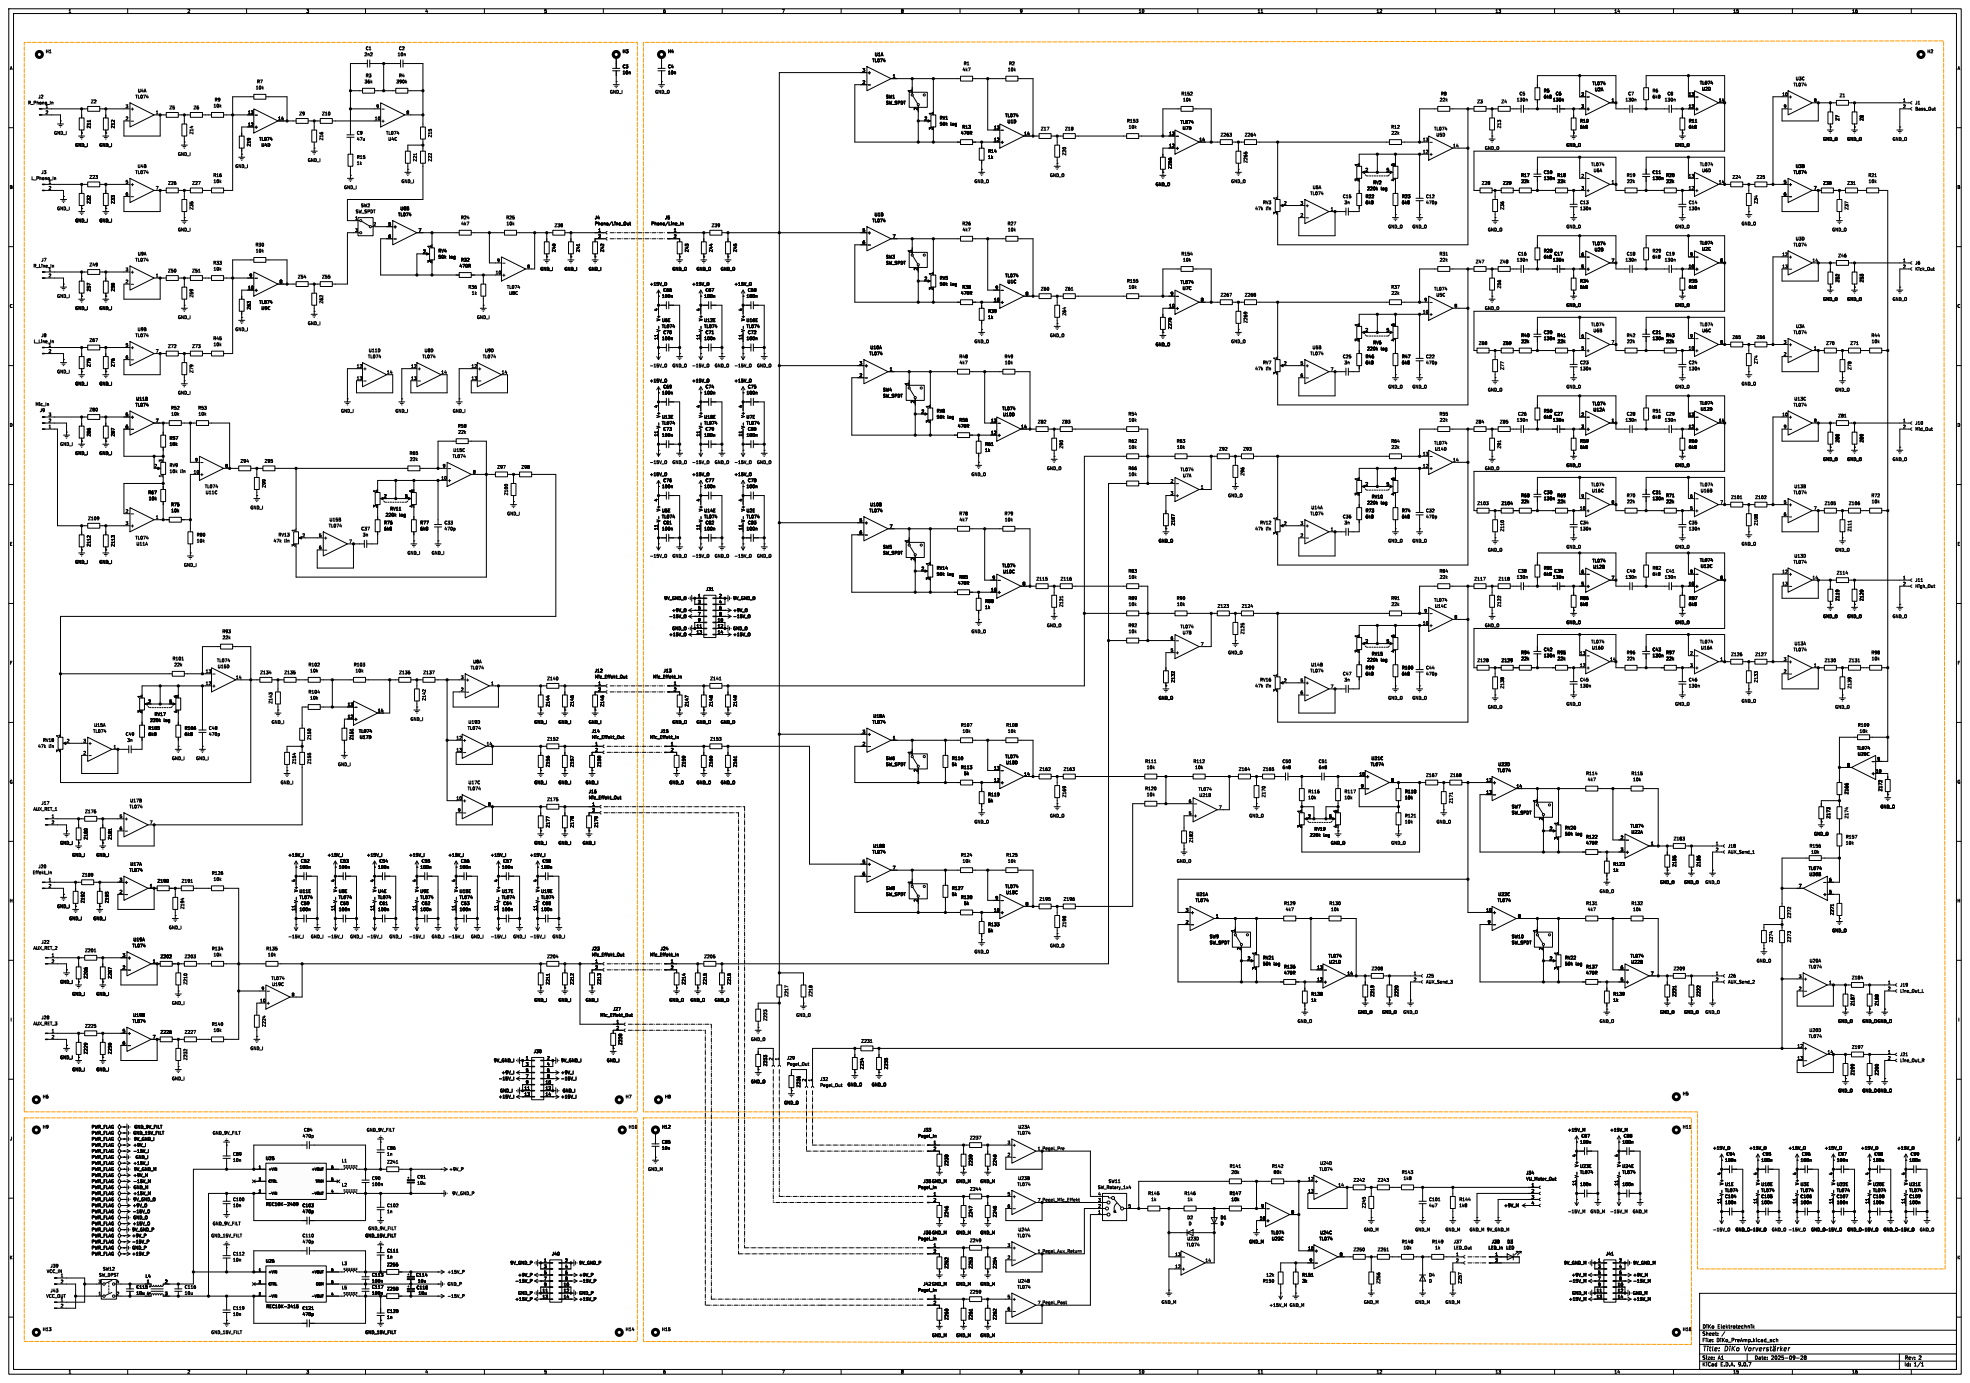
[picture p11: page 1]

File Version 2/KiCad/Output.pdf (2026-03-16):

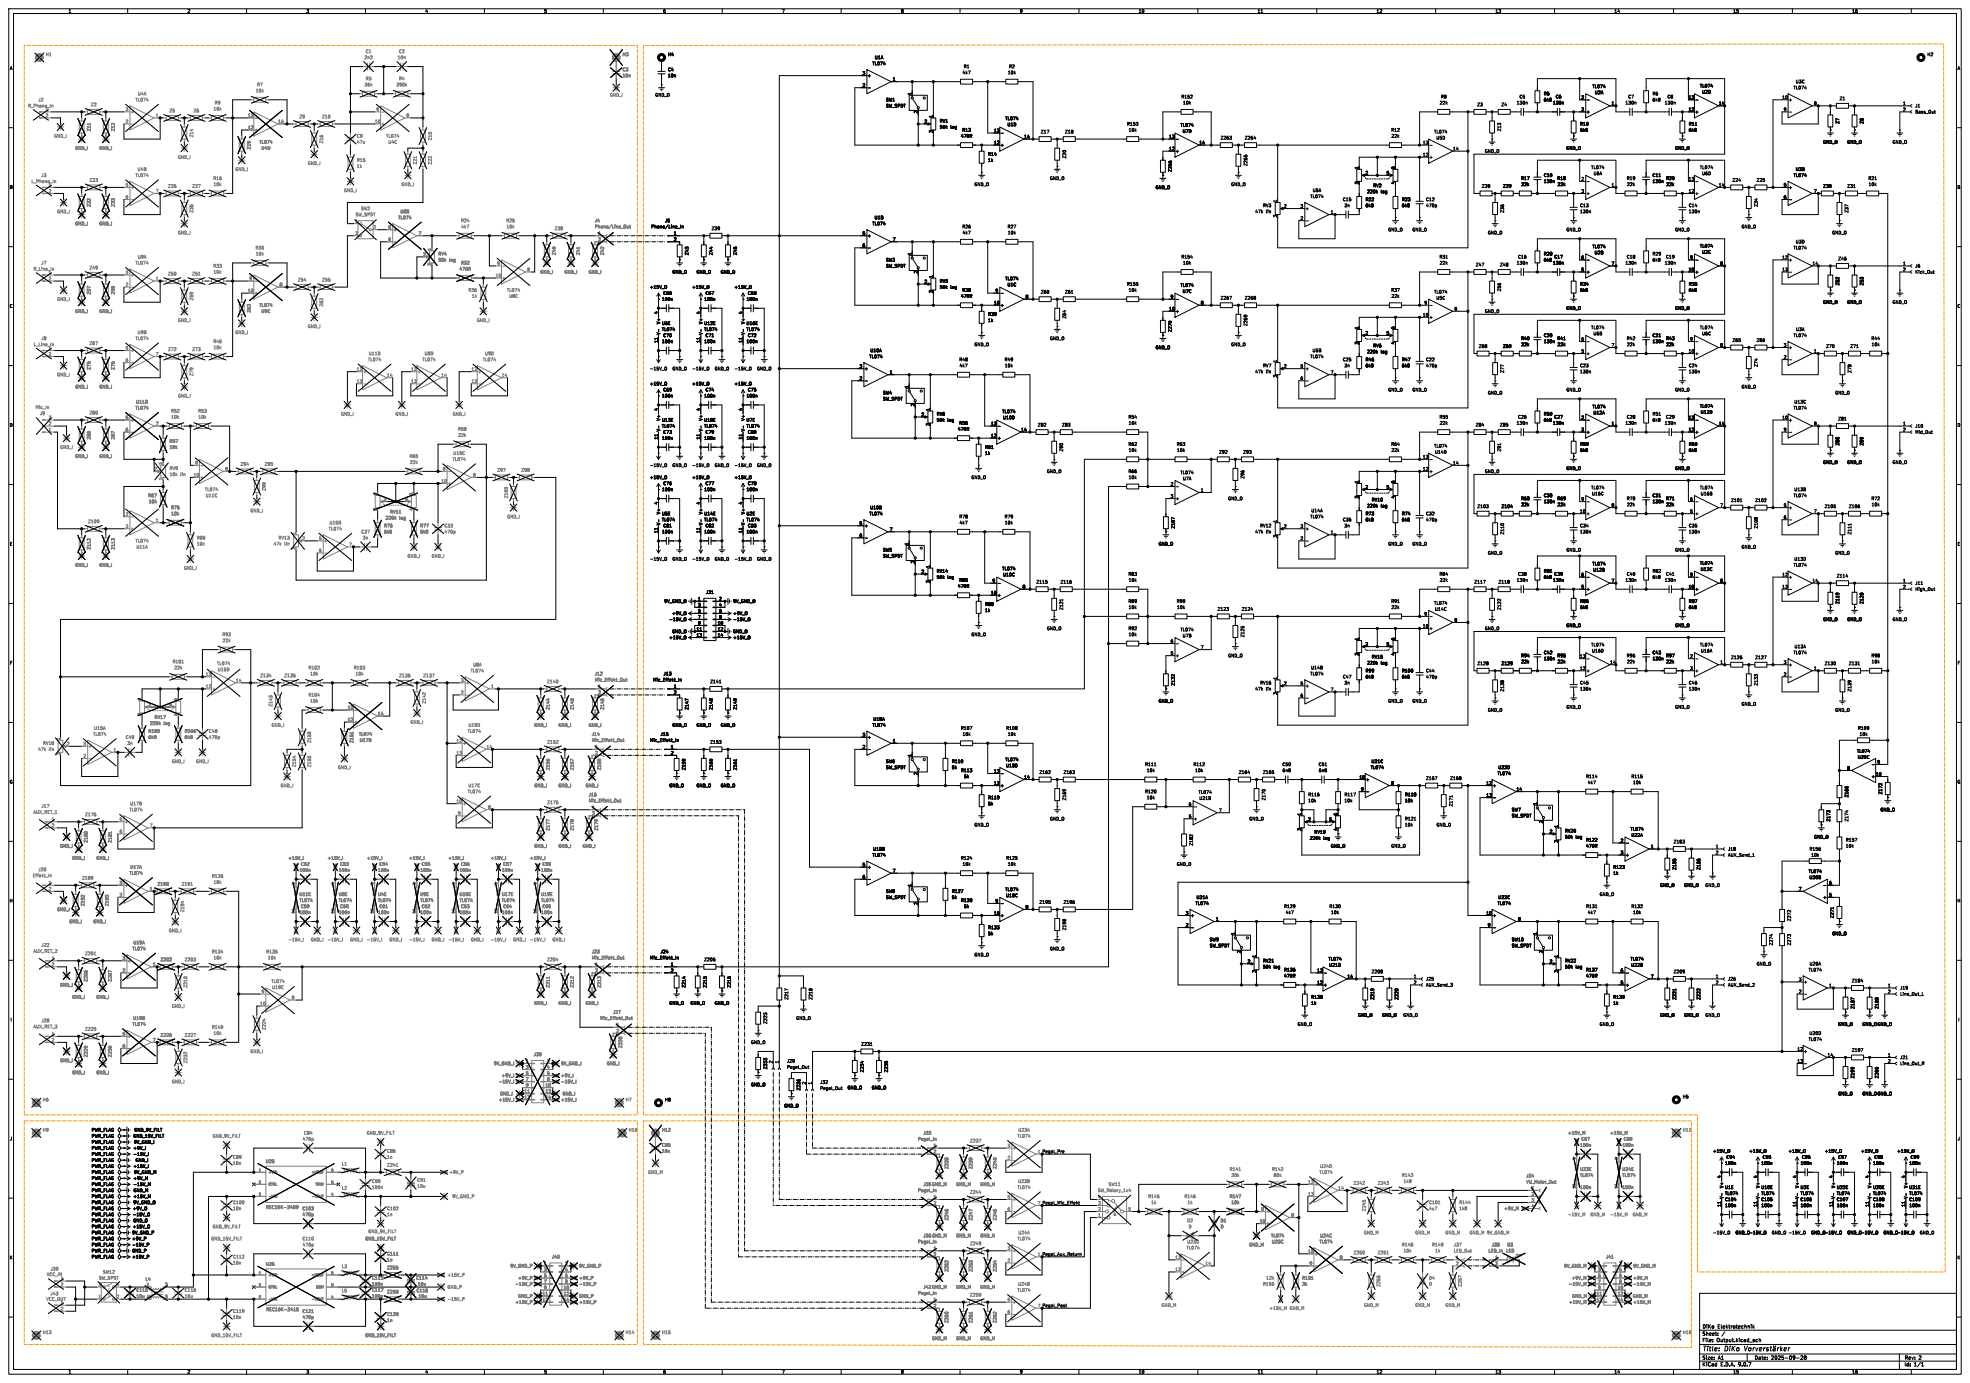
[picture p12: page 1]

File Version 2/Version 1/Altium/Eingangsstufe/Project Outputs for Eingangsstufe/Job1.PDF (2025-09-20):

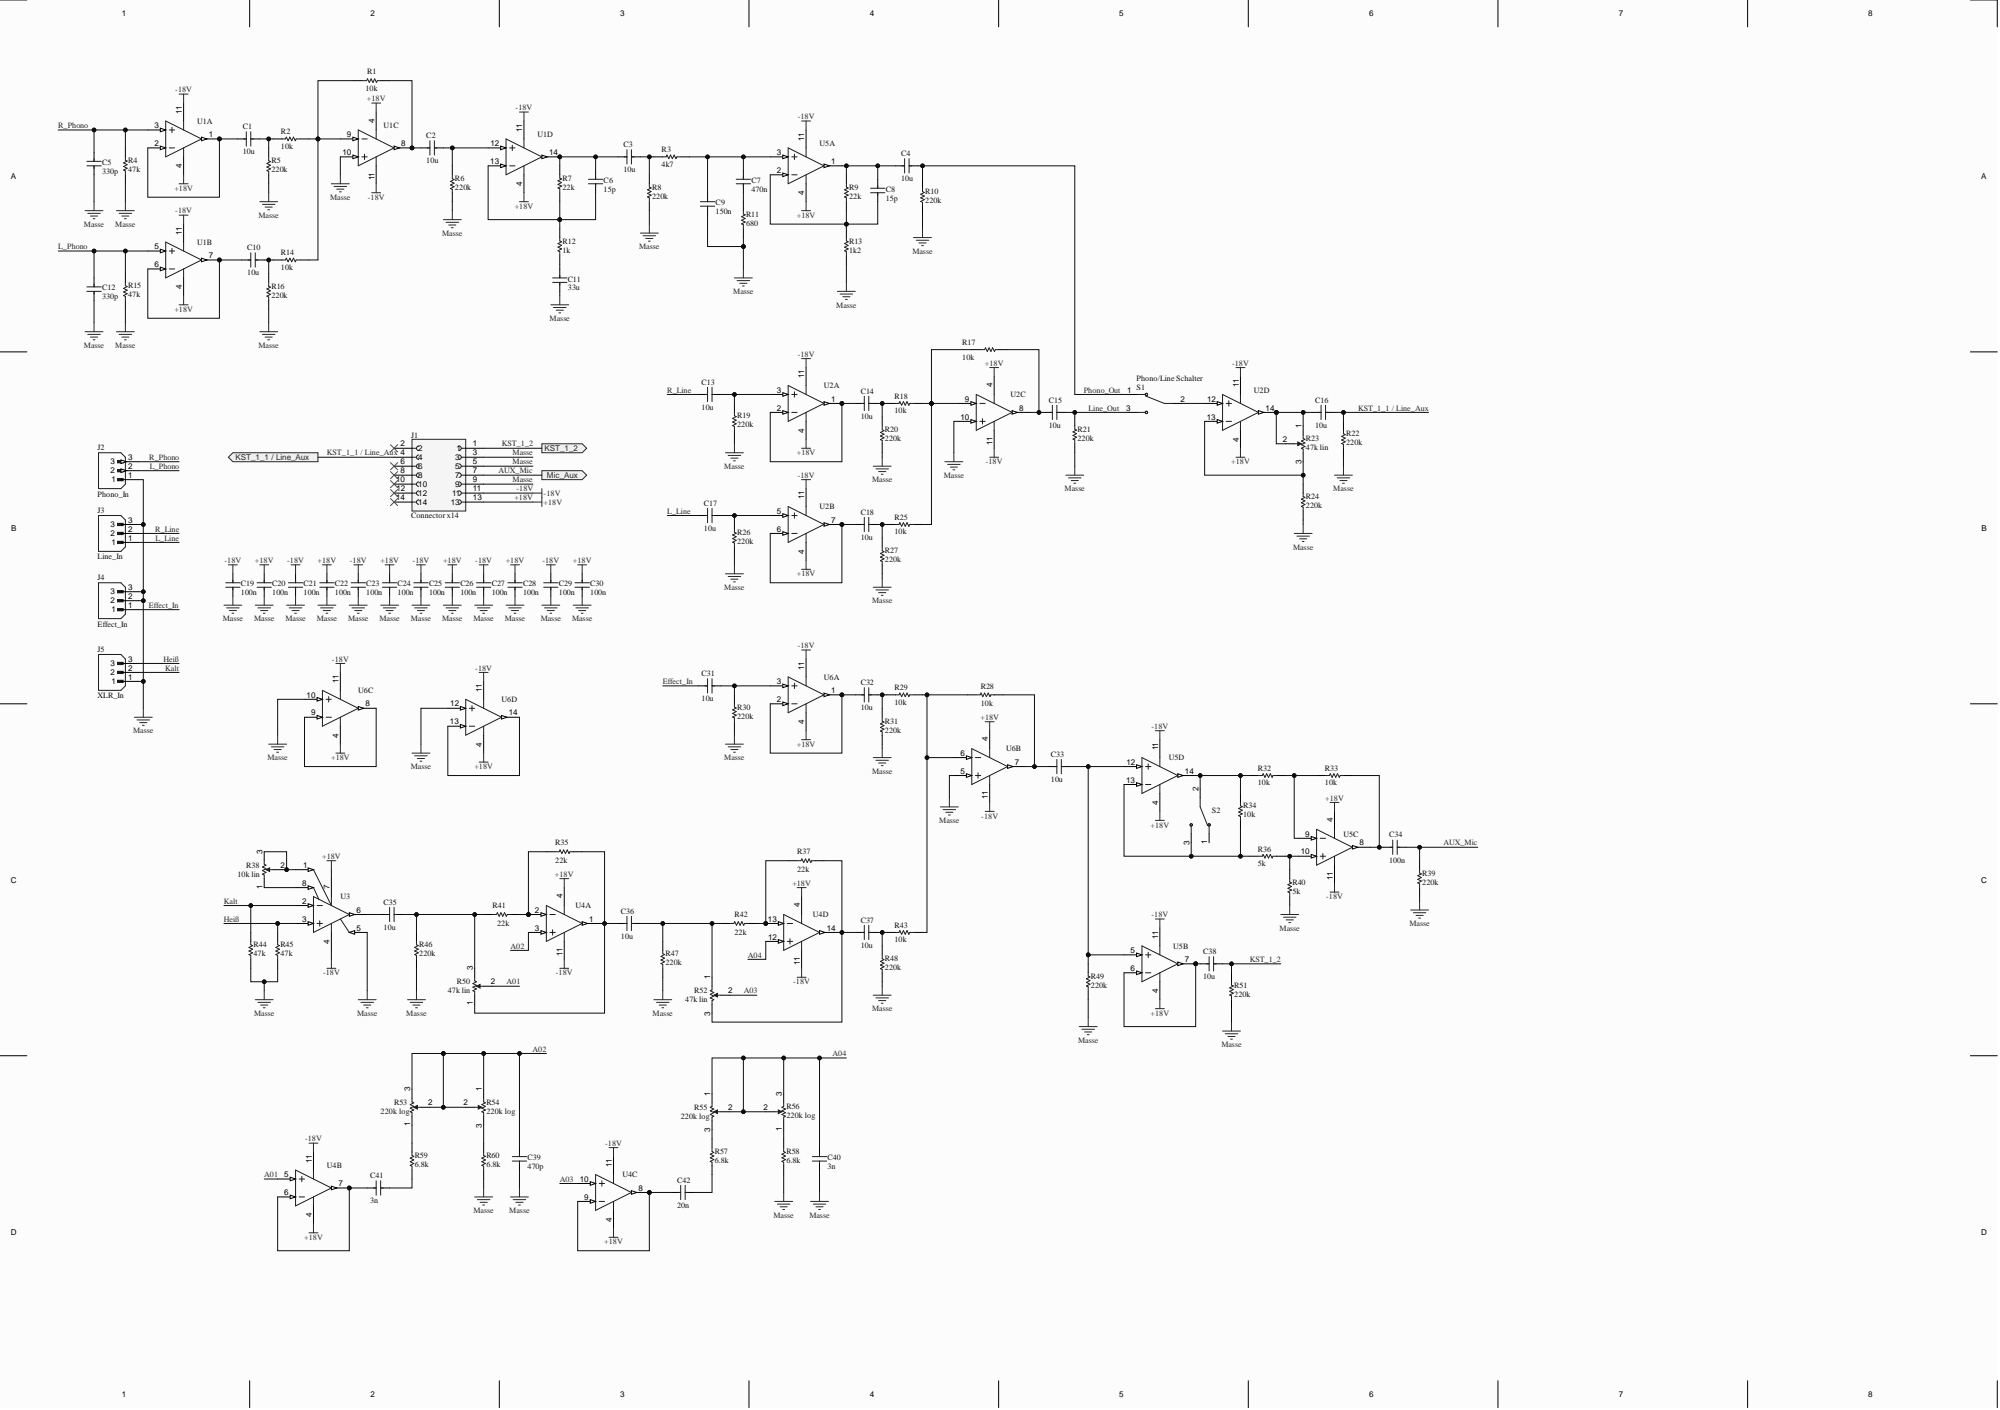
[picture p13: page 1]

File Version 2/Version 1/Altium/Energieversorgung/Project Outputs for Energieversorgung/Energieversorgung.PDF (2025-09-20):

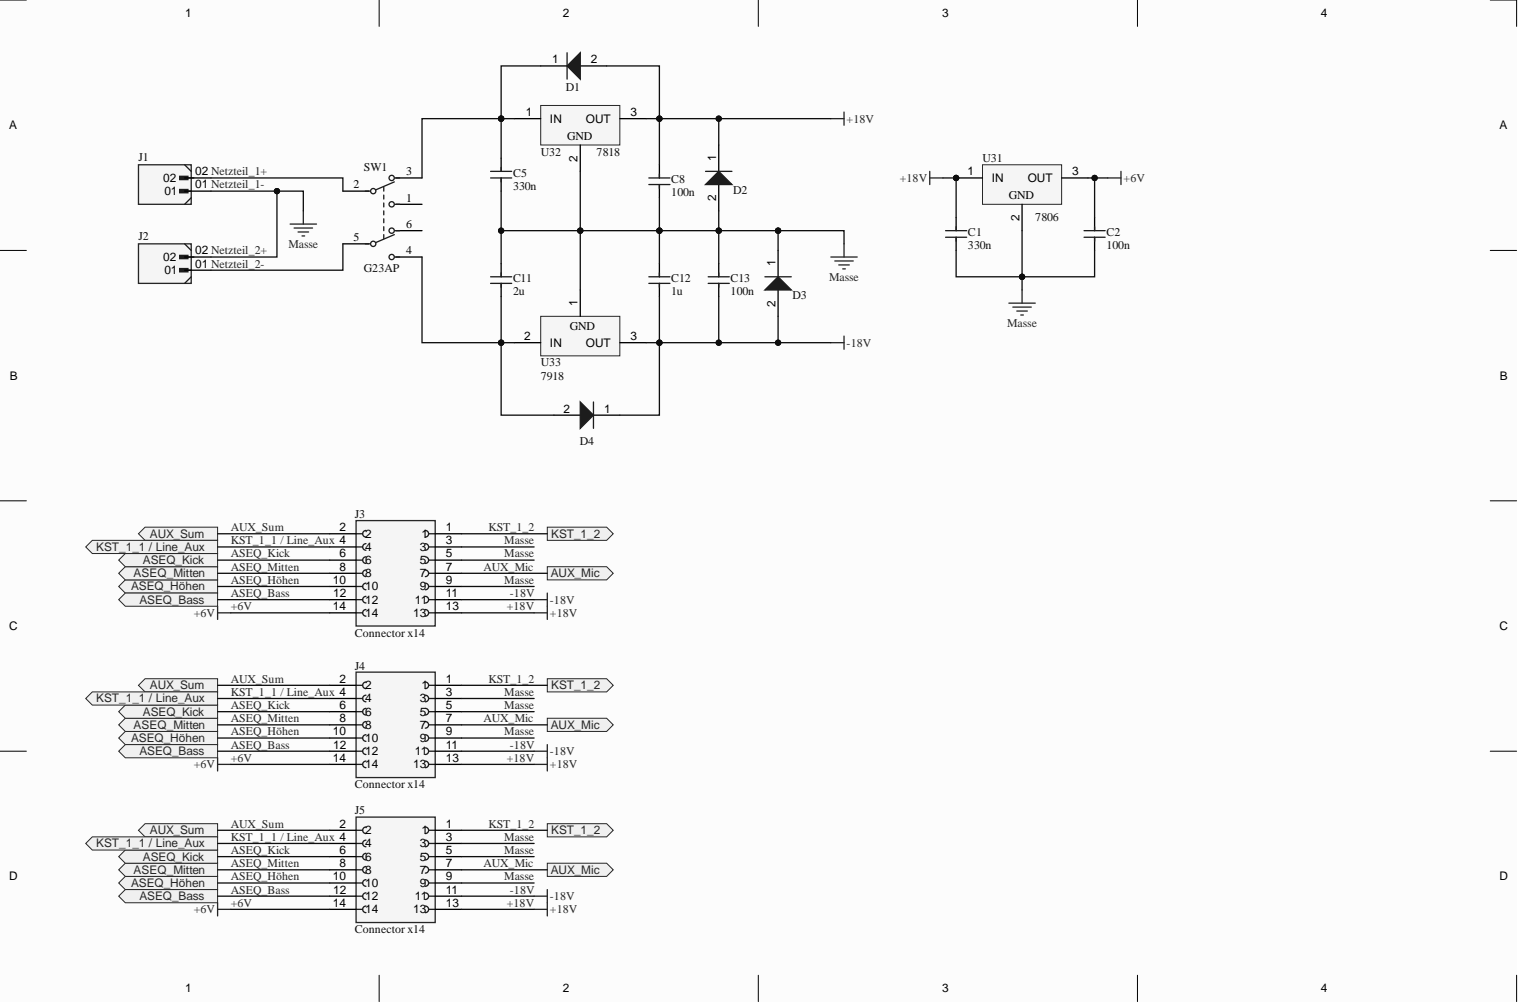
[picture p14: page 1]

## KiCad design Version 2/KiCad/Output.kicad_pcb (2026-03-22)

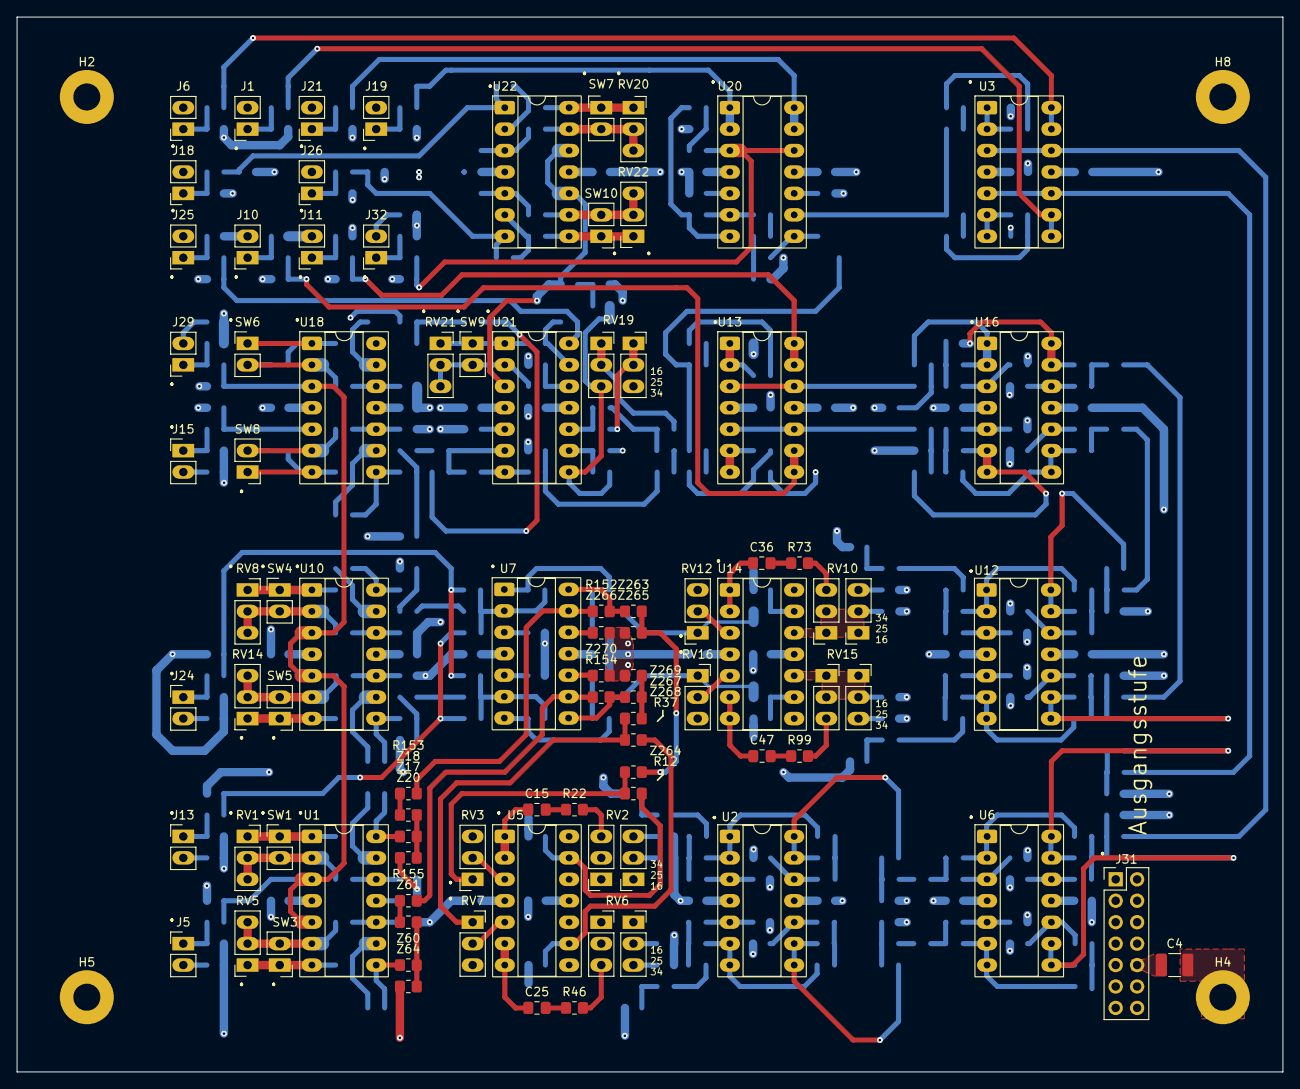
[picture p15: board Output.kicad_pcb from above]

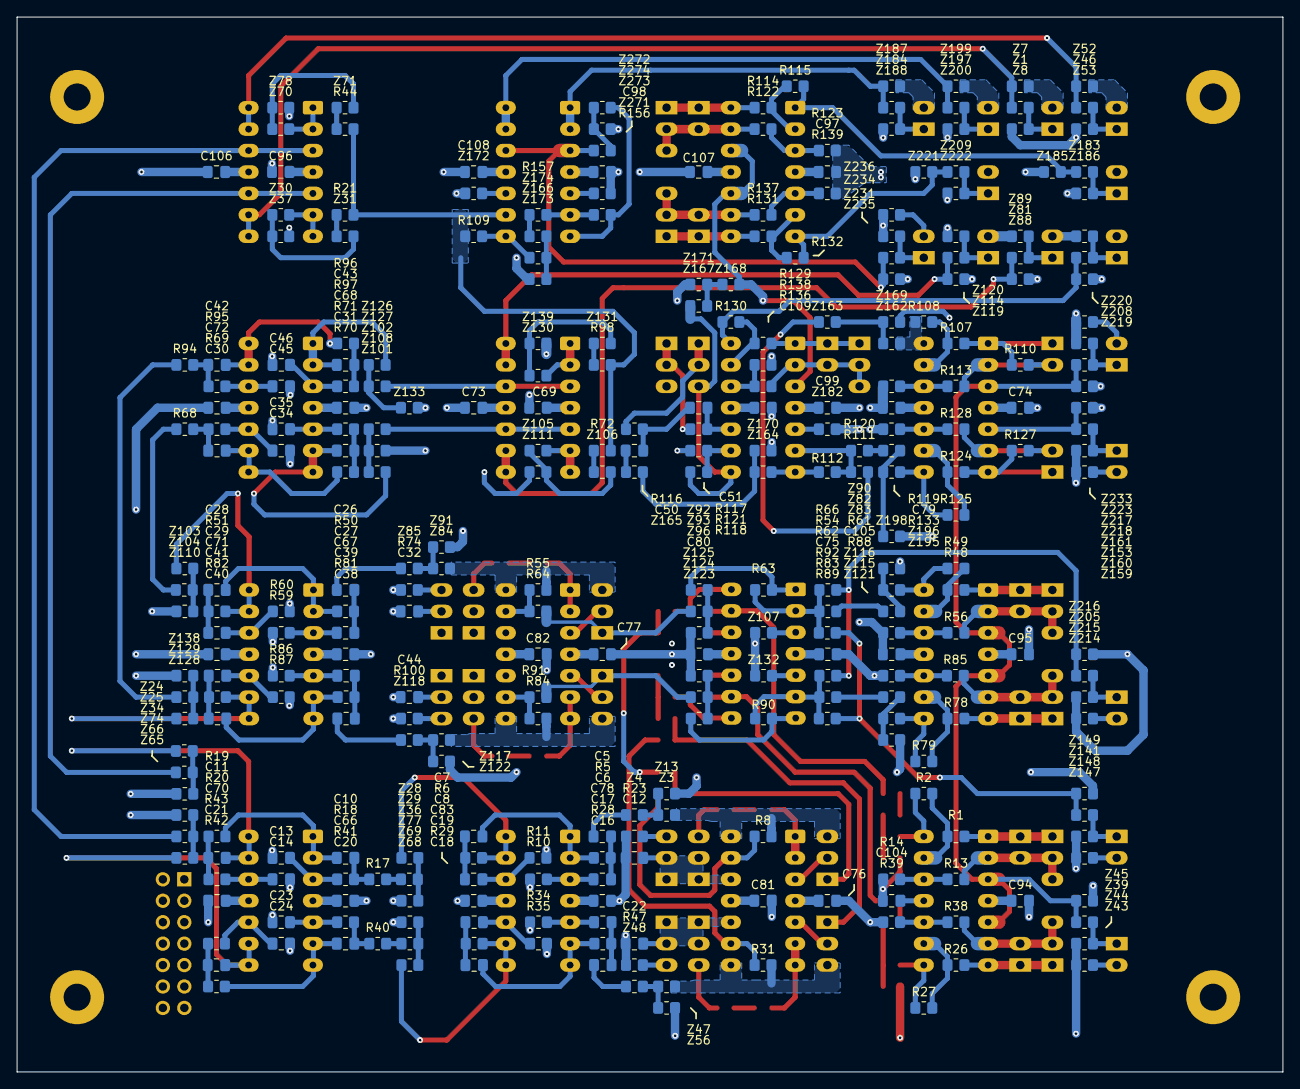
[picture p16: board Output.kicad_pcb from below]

Board: 4 copper layers, 150.0 x 125.0 mm, 393 parts (304 on the bottom side), 253 nets.

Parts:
C4: 10n; C_1210_3225Metric_Pad1.33x2.70mm_HandSolder
C5, C6, C7, C8, C10, C11, C13, C14, C16, C17, C18, C19, C20, C21, C23, C24, C26, C27, C28, C29, C30, C31, C34, C35, C38, C39, C40, C41, C42, C43, C45, C46: 130n; C_0805_2012Metric_Pad1.18x1.45mm_HandSolder
C12, C22, C32, C44: 470p; C_0805_2012Metric_Pad1.18x1.45mm_HandSolder
C15, C25, C36, C47: 3n; C_0805_2012Metric_Pad1.18x1.45mm_HandSolder
C50, C51: 6n8; C_0805_2012Metric_Pad1.18x1.45mm_HandSolder
C66, C67, C68, C69, C70, C71, C72, C73, C74, C75, C76, C77, C78, C79, C80, C81, C82, C83, C94, C95, C96, C97, C98, C99, C104, C105, C106, C107, C108, C109: 100n; C_0805_2012Metric_Pad1.18x1.45mm_HandSolder
H2, H5, H8: MountingHole; MountingHole_3.2mm_M3_Pad
H4: MountingHole_Pad; MountingHole_3.2mm_M3_Pad
J1: Bass_Out; PinSocket_1x02_P2.54mm_Vertical_LongPads
J5: Phono/Line_In; PinHeader_1x02_P2.54mm_Vertical_LongPads
J6: Kick_Out; PinSocket_1x02_P2.54mm_Vertical_LongPads
J10: Mid_Out; PinSocket_1x02_P2.54mm_Vertical_LongPads
J11: High_Out; PinSocket_1x02_P2.54mm_Vertical_LongPads
J13, J15, J24: Mic_Effekt_In; PinHeader_1x02_P2.54mm_Vertical_LongPads
J18: AUX_Send_1; PinSocket_1x02_P2.54mm_Vertical_LongPads
J19: Line_Out_L; PinSocket_1x02_P2.54mm_Vertical_LongPads
J21: Line_Out_R; PinSocket_1x02_P2.54mm_Vertical_LongPads
J25: AUX_Send_3; PinSocket_1x02_P2.54mm_Vertical_LongPads
J26: AUX_Send_2; PinSocket_1x02_P2.54mm_Vertical_LongPads
J29, J32: Pegel_Out; PinSocket_1x02_P2.54mm_Vertical_LongPads
J31: Conn_02x07_Odd_Even; PinHeader_2x07_P2.54mm_Vertical
R1, R26, R48, R78, R114, R129, R131: 4k7; R_0805_2012Metric_Pad1.20x1.40mm_HandSolder
R2, R21, R27, R44, R49, R54, R62, R63, R66, R72, R79, R83, R89, R90, R92, R98, R107, R108, R109, R111, R112, R115, R116, R117, R118, R120, R121, R124, R125, R130, R132, R152, R153, R154, R155, R156, R157: 10k; R_0805_2012Metric_Pad1.20x1.40mm_HandSolder
R5, R6, R10, R11, R22, R23, R28, R29, R34, R35, R46, R47, R50, R51, R59, R60, R73, R74, R81, R82, R86, R87, R99, R100: 6k8; R_0805_2012Metric_Pad1.20x1.40mm_HandSolder
R8, R12, R17, R18, R19, R20, R31, R37, R40, R41, R42, R43, R55, R64, R68, R69, R70, R71, R84, R91, R94, R95, R96, R97: 22k; R_0805_2012Metric_Pad1.20x1.40mm_HandSolder
R13, R38, R56, R85, R122, R136, R137: 470R; R_0805_2012Metric_Pad1.20x1.40mm_HandSolder
R14, R39, R61, R88, R123, R138, R139: 1k; R_0805_2012Metric_Pad1.20x1.40mm_HandSolder
R110, R113, R119, R127, R128, R133: 5k; R_0805_2012Metric_Pad1.20x1.40mm_HandSolder
RV1, RV5, RV8, RV14, RV20, RV21, RV22: 50k log; PinSocket_1x03_P2.54mm_Vertical_LongPads
RV2, RV10: 220k log; PinSocket_2x03_P2.54mm_Vertical_LongPads_Mirrored
RV3, RV7, RV12, RV16: 47k lin; PinSocket_1x03_P2.54mm_Vertical_LongPads
RV6, RV15, RV19: 220k log; PinSocket_2x03_P2.54mm_Vertical_LongPads
SW1, SW3, SW4, SW5, SW6, SW7, SW8, SW9, SW10: SW_SPDT; PinHeader_1x02_P2.54mm_Vertical_LongPads
U1, U2, U3, U5, U6, U7, U10, U12, U13, U14, U16, U18, U20, U21, U22: TL074; DIP-14_W7.62mm_Socket_LongPads
Z1, Z3, Z4, Z7, Z8, Z13, Z17, Z18, Z20, Z24, Z25, Z28, Z29, Z30, Z31, Z34, Z36, Z37, Z39, Z43, Z44, Z45, Z46, Z47, Z48, Z52, Z53, Z56, Z60, Z61, Z64, Z65, Z66, Z68, Z69, Z70, Z71, Z74, Z77, Z78, Z81, Z82, Z83, Z84, Z85, Z88, Z89, Z90, Z91, Z92, Z93, Z96, Z101, Z102, Z103, Z104, Z105, Z106, Z107, Z108, Z110, Z111, Z114, Z115, Z116, Z117, Z118, Z119, Z120, Z121, Z122, Z123, Z124, Z125, Z126, Z127, Z128, Z129, Z130, Z131, Z132, Z133, Z138, Z139, Z141, Z147, Z148, Z149, Z153, Z159, Z160, Z161, Z162, Z163, Z164, Z165, Z166, Z167, Z168, Z169, Z170, Z171, Z172, Z173, Z174, Z182, Z183, Z184, Z185, Z186, Z187, Z188, Z195, Z196, Z197, Z198, Z199, Z200, Z205, Z208, Z209, Z214, Z215, Z216, Z217, Z218, Z219, Z220, Z221, Z222, Z223, Z231, Z233, Z234, Z235, Z236, Z263, Z264, Z265, Z266, Z267, Z268, Z269, Z270, Z271, Z272, Z273, Z274: R_0805_2012Metric_Pad1.20x1.40mm_HandSolder

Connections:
9V_GND_O: J31.1, J31.2, J31.3, J31.4
+9V_O: J31.5, J31.6
+15V_O: C66.2, C67.2, C68.2, C69.2, C74.2, C75.2, C76.2, C77.2, C78.2, C94.2, C95.2, C96.2, C97.2, C98.2, C99.2, J31.13, J31.14, U1.4 (V+), U2.4 (V+), U3.4 (V+), U5.4 (V+), U6.4 (V+), U7.4 (V+), U10.4 (V+), U12.4 (V+), U13.4 (V+), U14.4 (V+), U16.4 (V+), U18.4 (V+), U20.4 (V+), U21.4 (V+), U22.4 (V+)
-15V_O: C70.2, C71.2, C72.2, C73.2, C79.2, C80.2, C81.2, C82.2, C83.2, C104.2, C105.2, C106.2, C107.2, C108.2, C109.2, J31.7, J31.8, U1.11 (V-), U2.11 (V-), U3.11 (V-), U5.11 (V-), U6.11 (V-), U7.11 (V-), U10.11 (V-), U12.11 (V-), U13.11 (V-), U14.11 (V-), U16.11 (V-), U18.11 (V-), U20.11 (V-), U21.11 (V-), U22.11 (V-)
GND_O: C4.2, C12.2, C13.1, C14.1, C22.2, C23.1, C24.1, C32.2, C34.1, C35.1, C44.2, C45.1, C46.1, C66.1, C67.1, C68.1, C69.1, C70.1, C71.1, C72.1, C73.1, C74.1, C75.1, C76.1, C77.1, C78.1, C79.1, C80.1, C81.1, C82.1, C83.1, C94.1, C95.1, C96.1, C97.1, C98.1, C99.1, C104.1, C105.1, C106.1, C107.1, C108.1, C109.1, J1.2, J6.2, J10.2, J11.2, J18.2, J19.2, J21.2, J25.2, J26.2, J31.9, J31.10, J31.11, J31.12, R10.1, R11.1, R14.1, R23.1, R34.1, R35.1, R39.1, R47.1, R59.1, R60.1, R61.1, R74.1, R86.1, R87.1, R88.1, R100.1, R119.2, R121.2, R123.2, R133.2, R138.2, R139.2, RV19.4, Z7.2, Z8.2, Z13.2, Z20.2, Z34.2, Z36.2, Z37.2, Z43.2, Z44.2, Z45.2, Z52.2, Z53.2, Z56.2, Z64.2, Z74.2, Z77.2, Z78.2, Z88.2, Z89.2, Z90.2, Z91.2, Z96.2, Z107.2, Z108.2, Z110.2, Z111.2, Z119.2, Z120.2, Z121.2, Z122.2, Z125.2, Z132.2, Z133.2, Z138.2, Z139.2, Z147.2, Z148.2, Z149.2, Z159.2, Z160.2, Z161.2, Z169.2, Z170.2, Z171.2, Z172.2, Z173.2, Z182.2, Z185.2, Z186.2, Z187.2, Z188.2, Z198.2, Z199.2, Z200.2, Z214.2, Z215.2, Z216.2, Z218.2, Z219.2, Z220.2, Z221.2, Z222.2, Z223.2, Z233.2, Z234.2, Z235.2, Z236.2, Z265.2, Z266.2, Z269.2, Z270.2, Z271.2, Z274.2
unnamed: C4.1, H4.1
unnamed: C5.1, Z4.2
unnamed: C5.2, C6.1, R5.1
unnamed: C7.2, C8.1, R6.1
unnamed: C10.1, R17.2, R18.1
unnamed: C11.1, R19.2, R20.1
unnamed: C15.1, R22.1
unnamed: C16.1, Z48.2
unnamed: C16.2, C17.1, R28.1
unnamed: C18.2, C19.1, R29.1
unnamed: C20.1, R40.2, R41.1
unnamed: C21.1, R42.2, R43.1
unnamed: C25.1, R46.1
unnamed: C26.1, Z85.2
unnamed: C26.2, C27.1, R50.1
unnamed: C28.2, C29.1, R51.1
unnamed: C30.1, R68.2, R69.1
unnamed: C31.1, R70.2, R71.1
unnamed: C36.1, R73.1
unnamed: C38.1, Z118.2
unnamed: C38.2, C39.1, R81.1
unnamed: C40.2, C41.1, R82.1
unnamed: C42.1, R94.2, R95.1
unnamed: C43.1, R96.2, R97.1
unnamed: C47.1, R99.1
unnamed: C50.1, C51.2, R116.1
unnamed: C50.2, Z165.2
unnamed: J1.1, Z1.2, Z8.1
unnamed: J5.1, Z39.1, Z44.1
unnamed: J5.2, Z43.1
unnamed: J6.1, Z46.2, Z53.1
unnamed: J10.1, Z81.2, Z89.1
unnamed: J11.1, Z114.2, Z120.1
unnamed: J13.1, Z141.1, Z148.1
unnamed: J13.2, Z147.1
unnamed: J15.1, Z153.1, Z160.1
unnamed: J15.2, Z159.1
unnamed: J18.1, Z183.2, Z186.1
unnamed: J19.1, Z184.2, Z188.1
unnamed: J21.1, Z197.2, Z200.1
unnamed: J24.1, Z205.1, Z215.1
unnamed: J24.2, Z214.1
unnamed: J25.1, Z208.2, Z220.1
unnamed: J26.1, Z209.2, Z222.1
unnamed: J29.1, Z217.2, Z223.1
unnamed: J29.2, Z233.1
unnamed: J32.1, Z231.1, Z234.1
unnamed: J32.2, Z236.1
unnamed: R2.2, U1.14, Z17.1
unnamed: R8.2, RV3.3, U5.14, Z3.1
unnamed: R12.1, RV3.1, Z264.2
unnamed: R17.1, Z29.2
unnamed: R21.1, Z31.2
unnamed: R22.2, RV2.3
unnamed: R23.2, RV2.4
unnamed: R27.2, U1.8, Z60.1
unnamed: R31.2, RV7.3, U5.8, Z47.1
unnamed: R37.1, RV7.1, Z268.2
unnamed: R40.1, Z69.2
unnamed: R44.1, Z71.2
unnamed: R46.2, RV6.3
unnamed: R47.2, RV6.4
unnamed: R49.2, U10.14, Z82.1
unnamed: R54.1, Z83.2
unnamed: R55.2, RV12.3, U14.14, Z84.1
unnamed: R62.1, R89.1, Z141.2, Z149.1
unnamed: R63.2, U7.1, Z92.1
unnamed: R64.1, RV12.1, Z93.2
unnamed: R66.1, R92.1, Z205.2, Z216.1
unnamed: R68.1, Z104.2
unnamed: R72.1, Z106.2
unnamed: R73.2, RV10.3
unnamed: R74.2, RV10.4
unnamed: R79.2, U10.8, Z115.1
unnamed: R83.1, Z116.2
unnamed: R84.2, RV16.3, U14.8, Z117.1
unnamed: R90.2, U7.7, Z123.1
unnamed: R91.1, RV16.1, Z124.2
unnamed: R94.1, Z129.2
unnamed: R98.1, Z131.2
unnamed: R99.2, RV15.3
unnamed: R100.2, RV15.4
unnamed: R108.1, U18.14, Z162.1
unnamed: R109.2, U20.8, Z166.1
unnamed: R111.2, Z163.2
unnamed: R112.1, U21.7, Z164.1
unnamed: R115.1, U22.1, Z183.1, Z185.1
unnamed: R116.2, RV19.1, RV19.2
unnamed: R117.2, RV19.5, RV19.6
unnamed: R118.1, RV19.3, U21.8, Z167.1
unnamed: R120.2, Z196.2
unnamed: R125.1, U18.8, Z195.1
unnamed: R130.1, U21.14, Z208.1, Z219.1
unnamed: R132.1, U22.7, Z209.1, Z221.1
unnamed: R152.2, U7.14, Z263.1
unnamed: R153.1, Z18.2
unnamed: R154.2, U7.8, Z267.1
unnamed: R155.1, Z61.2
unnamed: R156.1, U20.7, Z272.1
unnamed: R157.1, Z174.2
unnamed: R1.1, RV1.1, SW1.1 (A), U1.1
unnamed: R13.1, RV1.2, RV1.3, SW1.2 (B), U1.2 (-)
unnamed: R26.1, RV5.1, SW3.1 (A), U1.7
unnamed: R38.1, RV5.2, RV5.3, SW3.2 (B), U1.6 (-)
unnamed: R48.1, RV8.1, SW4.1 (A), U10.1
unnamed: R56.1, RV8.2, RV8.3, SW4.2 (B), U10.2 (-)
unnamed: R78.1, RV14.1, SW5.1 (A), U10.7
unnamed: R85.1, RV14.2, RV14.3, SW5.2 (B), U10.6 (-)
unnamed: R107.2, R110.1, SW6.1 (A), U18.1
unnamed: R110.2, R113.2, SW6.2 (B), U18.2 (-)
unnamed: R114.2, RV20.1, SW7.1 (A), U22.14
unnamed: R122.2, RV20.2, RV20.3, SW7.2 (B), U22.13 (-)
unnamed: R124.2, R127.1, SW8.1 (A), U18.7
unnamed: R127.2, R128.2, SW8.2 (B), U18.6 (-)
unnamed: R129.2, RV21.1, SW9.1 (A), U21.1
unnamed: R136.2, RV21.2, RV21.3, SW9.2 (B), U21.2 (-)
unnamed: R131.2, RV22.1, SW10.1 (A), U22.8
unnamed: R137.2, RV22.2, RV22.3, SW10.2 (B), U22.9 (-)
unnamed: R38.2, R39.2, U1.10 (+)
unnamed: R26.2, R27.1, U1.9 (-)
unnamed: R13.2, R14.2, U1.12 (+)
unnamed: R1.2, R2.1, U1.13 (-)
unnamed: C6.2, R10.2, U2.3 (+)
unnamed: C7.1, R5.2, U2.1, U2.2 (-)
unnamed: C17.2, R34.2, U2.5 (+)
unnamed: C18.1, R28.2, U2.6 (-), U2.7
unnamed: C19.2, R35.2, U2.10 (+)
unnamed: R29.2, U2.8, U2.9 (-), Z68.1
unnamed: C8.2, R11.2, U2.12 (+)
unnamed: R6.2, U2.13 (-), U2.14, Z28.1
unnamed: U3.3 (+), U3.12 (+), Z66.2
unnamed: U3.1, U3.2 (-), Z70.1
unnamed: U3.5 (+), U3.10 (+), Z25.2
unnamed: U3.6 (-), U3.7, Z30.1
unnamed: U3.8, U3.9 (-), Z1.1, Z7.1
unnamed: U3.13 (-), U3.14, Z46.1, Z52.1
unnamed: RV3.2, U5.3 (+)
unnamed: C15.2, U5.1, U5.2 (-)
unnamed: RV7.2, U5.5 (+)
unnamed: C25.2, U5.6 (-), U5.7
unnamed: C22.1, RV6.1, RV6.2, RV6.5, RV6.6, U5.10 (+)
unnamed: R31.1, R37.2, U5.9 (-)
unnamed: C12.1, RV2.1, RV2.2, RV2.5, RV2.6, U5.12 (+)
unnamed: R8.1, R12.2, U5.13 (-)
unnamed: C13.2, R18.2, U6.3 (+)
unnamed: C10.2, R19.1, U6.1, U6.2 (-)
unnamed: C23.2, R41.2, U6.5 (+)
unnamed: C20.2, R42.1, U6.6 (-), U6.7
unnamed: C24.2, R43.2, U6.10 (+)
unnamed: C21.2, U6.8, U6.9 (-), Z65.1
unnamed: C14.2, R20.2, U6.12 (+)
unnamed: C11.2, U6.13 (-), U6.14, Z24.1
unnamed: U7.3 (+), Z107.1
unnamed: R54.2, R62.2, R63.1, R66.2, U7.2 (-)
unnamed: U7.5 (+), Z132.1
unnamed: R83.2, R89.2, R90.1, R92.2, U7.6 (-)
unnamed: U7.10 (+), Z270.1
unnamed: R154.1, R155.2, U7.9 (-)
unnamed: U7.12 (+), Z266.1
unnamed: R152.1, R153.2, U7.13 (-)
unnamed: U1.3 (+), U1.5 (+), U10.3 (+), U10.5 (+), U18.3 (+), Z39.2, Z45.1, Z217.1, Z218.1
unnamed: R85.2, R88.2, U10.10 (+)
unnamed: R78.2, R79.1, U10.9 (-)
unnamed: R56.2, R61.2, U10.12 (+)
unnamed: R48.2, R49.1, U10.13 (-)
unnamed: C27.2, R59.2, U12.3 (+)
unnamed: C28.1, R50.2, U12.1, U12.2 (-)
unnamed: C39.2, R86.2, U12.5 (+)
unnamed: C40.1, R81.2, U12.6 (-), U12.7
unnamed: C41.2, R87.2, U12.10 (+)
unnamed: R82.2, U12.8, U12.9 (-), Z128.1
unnamed: C29.2, R60.2, U12.12 (+)
unnamed: R51.2, U12.13 (-), U12.14, Z103.1
unnamed: U13.3 (+), U13.12 (+), Z127.2
unnamed: U13.1, U13.2 (-), Z130.1
unnamed: U13.5 (+), U13.10 (+), Z102.2
unnamed: U13.6 (-), U13.7, Z105.1
unnamed: U13.8, U13.9 (-), Z81.1, Z88.1
unnamed: U13.13 (-), U13.14, Z114.1, Z119.1
unnamed: RV12.2, U14.3 (+)
unnamed: C36.2, U14.1, U14.2 (-)
unnamed: RV16.2, U14.5 (+)
unnamed: C47.2, U14.6 (-), U14.7
unnamed: C44.1, RV15.1, RV15.2, RV15.5, RV15.6, U14.10 (+)
unnamed: R84.1, R91.2, U14.9 (-)
unnamed: C32.1, RV10.1, RV10.2, RV10.5, RV10.6, U14.12 (+)
unnamed: R55.1, R64.2, U14.13 (-)
unnamed: C46.2, R97.2, U16.3 (+)
unnamed: C43.2, U16.1, U16.2 (-), Z126.1
unnamed: C35.2, R71.2, U16.5 (+)
unnamed: C31.2, U16.6 (-), U16.7, Z101.1
unnamed: C34.2, R69.2, U16.10 (+)
unnamed: C30.2, R70.1, U16.8, U16.9 (-)
unnamed: C45.2, R95.2, U16.12 (+)
unnamed: C42.2, R96.1, U16.13 (-), U16.14
unnamed: U18.5 (+), Z153.2, Z161.1
unnamed: R128.1, R133.1, U18.10 (+)
unnamed: R124.1, R125.2, U18.9 (-)
unnamed: R113.1, R119.1, U18.12 (+)
unnamed: R107.1, R108.2, U18.13 (-)
unnamed: U20.3 (+), U20.12 (+), Z231.2, Z235.1, Z273.2
unnamed: U20.1, U20.2 (-), Z184.1, Z187.1
unnamed: U20.5 (+), Z271.1
unnamed: R156.2, R157.2, U20.6 (-)
unnamed: U20.10 (+), Z172.1
unnamed: R21.2, R44.2, R72.2, R98.2, R109.1, U20.9 (-)
unnamed: U20.13 (-), U20.14, Z197.1, Z199.1
unnamed: U21.3 (+), U22.10 (+), U22.12 (+), Z168.2
unnamed: U21.5 (+), Z182.1
unnamed: R111.1, R112.2, R120.1, U21.6 (-)
unnamed: C51.1, R117.1, U21.10 (+)
unnamed: R118.2, R121.1, U21.9 (-)
unnamed: R136.1, R138.1, U21.12 (+)
unnamed: R129.1, R130.2, U21.13 (-)
unnamed: R122.1, R123.1, U22.3 (+)
unnamed: R114.1, R115.2, U22.2 (-)
unnamed: R137.1, R139.1, U22.5 (+)
unnamed: R131.1, R132.2, U22.6 (-)
unnamed: Z3.2, Z4.1, Z13.1
unnamed: Z17.2, Z18.1, Z20.1
unnamed: Z24.2, Z25.1, Z34.1
unnamed: Z28.2, Z29.1, Z36.1
unnamed: Z30.2, Z31.1, Z37.1
unnamed: Z47.2, Z48.1, Z56.1
unnamed: Z60.2, Z61.1, Z64.1
unnamed: Z65.2, Z66.1, Z74.1
unnamed: Z68.2, Z69.1, Z77.1
unnamed: Z70.2, Z71.1, Z78.1
unnamed: Z82.2, Z83.1, Z90.1
unnamed: Z84.2, Z85.1, Z91.1
unnamed: Z92.2, Z93.1, Z96.1
unnamed: Z101.2, Z102.1, Z108.1
unnamed: Z103.2, Z104.1, Z110.1
unnamed: Z105.2, Z106.1, Z111.1
unnamed: Z115.2, Z116.1, Z121.1
unnamed: Z117.2, Z118.1, Z122.1
unnamed: Z123.2, Z124.1, Z125.1
unnamed: Z126.2, Z127.1, Z133.1
unnamed: Z128.2, Z129.1, Z138.1
unnamed: Z130.2, Z131.1, Z139.1
unnamed: Z162.2, Z163.1, Z169.1
unnamed: Z164.2, Z165.1, Z170.1
unnamed: Z166.2, Z173.1, Z174.1
unnamed: Z167.2, Z168.1, Z171.1
unnamed: Z195.2, Z196.1, Z198.1
unnamed: Z263.2, Z264.1, Z265.1
unnamed: Z267.2, Z268.1, Z269.1
unnamed: Z272.2, Z273.1, Z274.1

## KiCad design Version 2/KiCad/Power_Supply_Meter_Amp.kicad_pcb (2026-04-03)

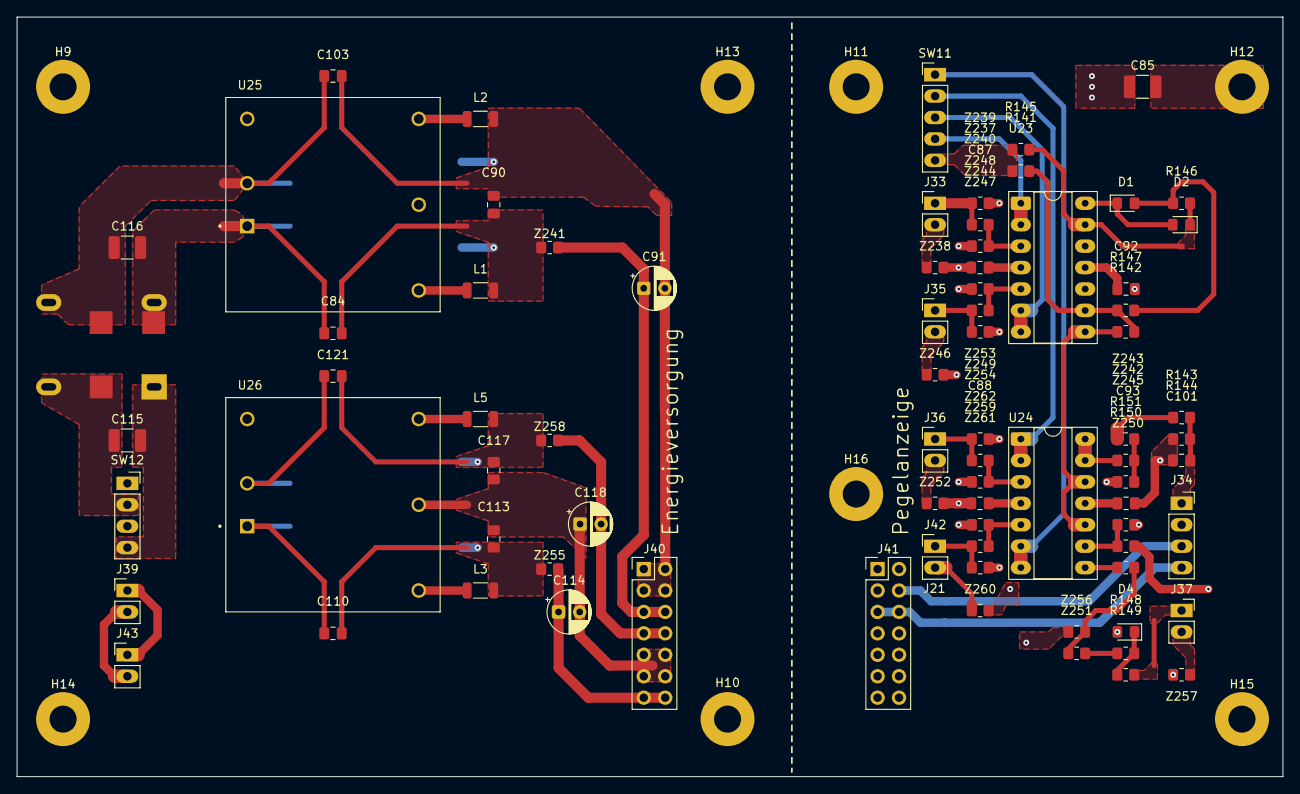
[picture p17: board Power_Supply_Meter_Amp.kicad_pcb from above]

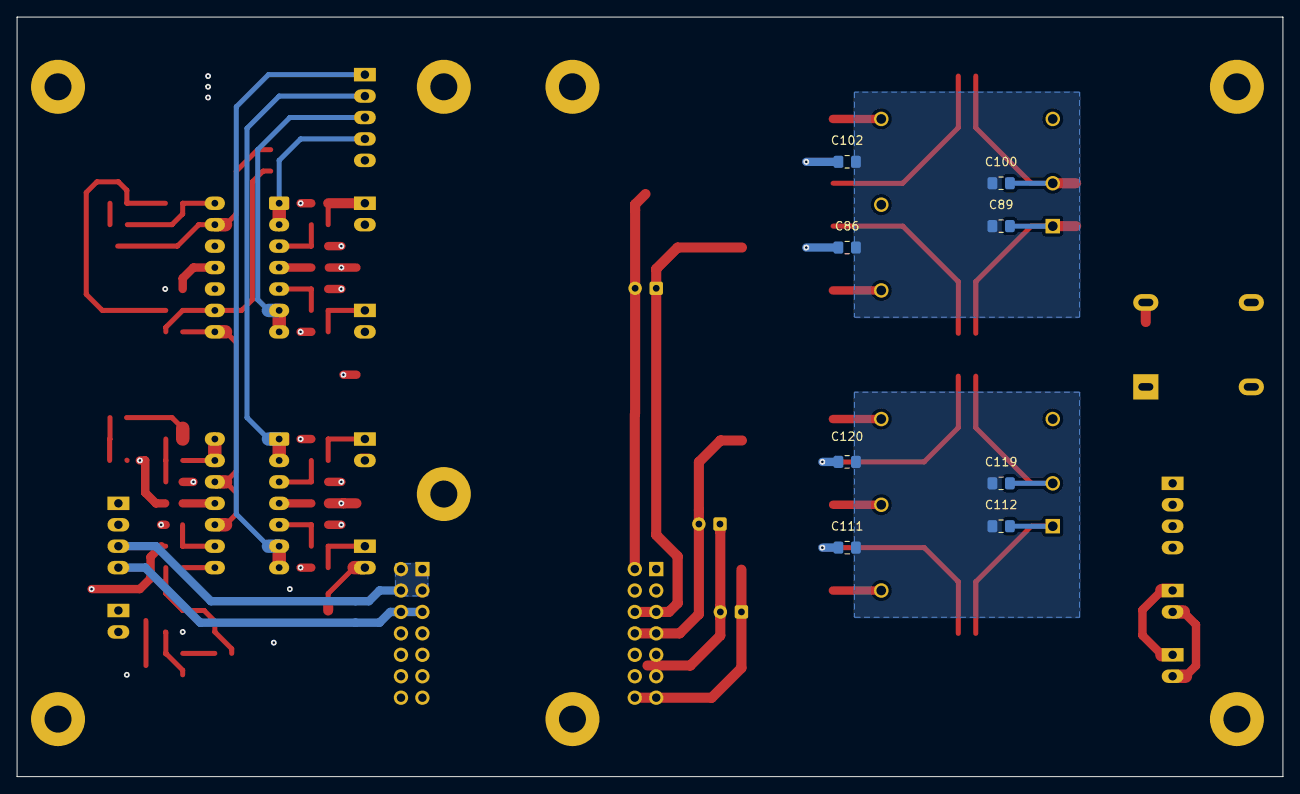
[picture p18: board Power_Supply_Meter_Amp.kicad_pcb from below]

Board: 4 copper layers, 150.0 x 90.0 mm, 95 parts (8 on the bottom side), 59 nets.

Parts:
C84, C103, C110, C121: 470p; C_0805_2012Metric_Pad1.18x1.45mm_HandSolder
C85: 10n; C_1210_3225Metric_Pad1.33x2.70mm_HandSolder
C86, C102, C111, C120: 1n; C_0805_2012Metric_Pad1.18x1.45mm_HandSolder
C87, C88, C90, C92, C93, C113, C117: 100n; C_0805_2012Metric_Pad1.18x1.45mm_HandSolder
C89, C100, C112, C119: 10n; C_0805_2012Metric_Pad1.18x1.45mm_HandSolder
C91, C114, C118: 10u; CP_Radial_D5.0mm_P2.50mm
C101: 4u7; C_0805_2012Metric_Pad1.18x1.45mm_HandSolder
C115, C116: 10u; C_1210_3225Metric_Pad1.33x2.70mm_HandSolder
D1, D2, D4: D; D_0805_2012Metric_Pad1.15x1.40mm_HandSolder
H9, H10, H11, H13, H14, H15, H16: MountingHole; MountingHole_3.2mm_M3_Pad
H12: MountingHole_Pad; MountingHole_3.2mm_M3_Pad
J33, J35, J36, J42: Pegel_In; PinHeader_1x02_P2.54mm_Vertical_LongPads
J34: VU_Meter_Out; PinSocket_1x04_P2.54mm_Vertical_LongPdas
J37: LED_Out; PinSocket_1x02_P2.54mm_Vertical_LongPads
J39: VCC_IN; PinHeader_1x02_P2.54mm_Vertical_LongPads
J40, J41: Conn_02x07_Odd_Even; PinHeader_2x07_P2.54mm_Vertical
J43: VCC_OUT; PinHeader_1x02_P2.54mm_Vertical_LongPads
L1, L2, L3, L5: Dämpfungsperle, 220 Ohm @ 100MHz, 0.5A; L_1206_3216Metric
L4: WE-SL575
R141: 20k; R_0805_2012Metric_Pad1.20x1.40mm_HandSolder
R142: 80k; R_0805_2012Metric_Pad1.20x1.40mm_HandSolder
R143, R144: 1k8; R_0805_2012Metric_Pad1.20x1.40mm_HandSolder
R145, R146, R149: 1k; R_0805_2012Metric_Pad1.20x1.40mm_HandSolder
R147, R148: 10k; R_0805_2012Metric_Pad1.20x1.40mm_HandSolder
R150: 12k; R_0805_2012Metric_Pad1.20x1.40mm_HandSolder
R151: 3k; R_0805_2012Metric_Pad1.20x1.40mm_HandSolder
SW11: SW_Rotary_1x4; PinHeader_1x05_P2.54mm_Vertical_LongPads
SW12: SW_DPST; PinSocket_1x04_P2.54mm_Vertical_LongPdas
U23, U24: TL074; DIP-14_W7.62mm_Socket_LongPads
U25: REC10K-2409; CONV_REC10K-2409SAW_H2
U26: REC10K-2415; CONV_REC10K-2415DAW_H2
Z237, Z238, Z239, Z240, Z241, Z242, Z243, Z244, Z245, Z246, Z247, Z248, Z249, Z250, Z251, Z252, Z253, Z254, Z255, Z256, Z257, Z258, Z259, Z260, Z261, Z262: R_0805_2012Metric_Pad1.20x1.40mm_HandSolder

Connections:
9V_GND_M: J34.3, J41.1, J41.2, J41.3, J41.4
9V_GND_P: C90.2, C91.2, C102.1, C103.2, J40.1, J40.2, J40.3, J40.4, L2.2
+9V_M: J34.4, J41.5, J41.6
+9V_P: C91.1, J40.5, J40.6, Z241.2
+15V_M: C87.2, C88.2, J41.13, J41.14, R150.1, U23.4 (V+), U24.4 (V+)
+15V_P: C114.1, J40.13, J40.14, Z255.2
-15V_M: C92.2, C93.2, J41.7, J41.8, U23.11 (V-), U24.11 (V-)
-15V_P: C118.2, J40.7, J40.8, Z258.2
/Pegel_Aux_Return: SW11.2, U24.1, U24.2 (-)
/Pegel_Mic_Effekt: SW11.3, U23.6 (-), U23.7
/Pegel_Post: SW11.1, U24.6 (-), U24.7
/Pegel_Pre: SW11.4, U23.1, U23.2 (-)
GND_9V_FILT: C86.1, C89.1, C100.2, C102.2
GND_15V_FILT: C111.1, C112.1, C119.2, C120.2
GND_M: C85.2, C87.1, C88.1, C92.1, C93.1, C101.2, D4.2 (A), J34.2, J41.9, J41.10, J41.11, J41.12, R144.1, R151.1, U23.10 (+), U23.12 (+), Z238.2, Z239.2, Z240.2, Z245.2, Z246.2, Z247.2, Z248.2, Z252.2, Z253.2, Z254.2, Z256.2, Z257.2, Z260.2, Z261.2, Z262.2
GND_P: C113.2, C114.2, C117.1, C118.1, J40.9, J40.10, J40.11, J40.12, U26.5 (COM)
unnamed: C84.2, C86.2, C90.1, L1.2, Z241.1
unnamed: C85.1, H12.1
unnamed: C110.2, C111.2, C113.1, L3.2, Z255.1
unnamed: C115.1, L4.1, SW12.4
unnamed: C115.2, L4.4, SW12.2
unnamed: C117.2, C120.1, C121.2, L5.2, Z258.1
unnamed: D1.2 (A), R146.2, R147.1
unnamed: D1.1 (K), D2.2 (A), U23.14
unnamed: D2.1 (K), R145.2, R146.1, U23.13 (-)
unnamed: D4.1 (K), R148.1, R149.2
unnamed: J33.1, Z237.1, Z239.1
unnamed: J33.2, Z238.1
unnamed: C101.1, J34.1, R143.2, R144.2
unnamed: J35.1, Z244.1, Z247.1
unnamed: J35.2, Z246.1
unnamed: J36.1, Z249.1, Z253.1
unnamed: J36.2, Z252.1
unnamed: J37.1, R149.1
unnamed: J37.2, Z257.1
unnamed: J39.1, J43.1, SW12.3
unnamed: J39.2, J43.2, SW12.1
unnamed: J42.1, Z259.1, Z261.1
unnamed: J42.2, Z260.1
unnamed: R141.1, R145.1, SW11.5
unnamed: R143.1, Z243.2
unnamed: R148.2, Z251.2
unnamed: U23.3 (+), Z237.2, Z240.1
unnamed: U23.5 (+), Z244.2, Z248.1
unnamed: R141.2, R142.1, R147.2, U23.9 (-)
unnamed: U24.8, Z250.1
unnamed: U24.3 (+), Z249.2, Z254.1
unnamed: U24.5 (+), Z259.2, Z262.1
unnamed: R142.2, U23.8, U24.10 (+), U24.12 (+)
unnamed: R150.2, R151.2, U24.9 (-)
unnamed: U24.13 (-), U24.14, Z242.1
unnamed: C84.1, C89.2, C110.1, C112.2, C116.1, L4.2, U25.1 (+VIN), U26.1 (+VIN)
unnamed: L1.1, U25.6 (+VOUT)
unnamed: C100.1, C103.1, C116.2, C119.1, C121.1, L4.3, U25.2 (-VIN), U26.2 (-VIN)
unnamed: L2.1, U25.4 (-VOUT)
unnamed: L3.1, U26.6 (+VOUT)
unnamed: L5.1, U26.4 (-VOUT)
unnamed: Z242.2, Z243.1, Z245.1
unnamed: Z250.2, Z251.1, Z256.1

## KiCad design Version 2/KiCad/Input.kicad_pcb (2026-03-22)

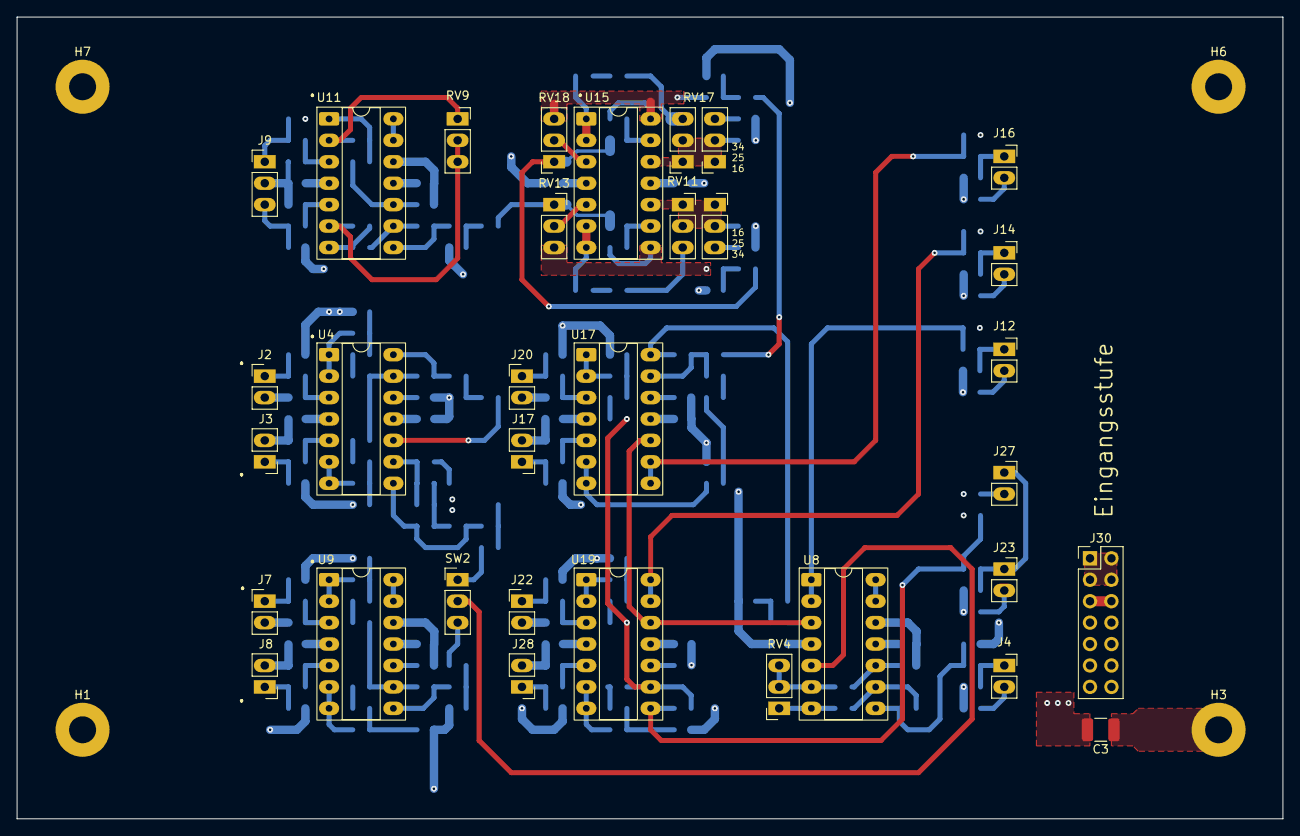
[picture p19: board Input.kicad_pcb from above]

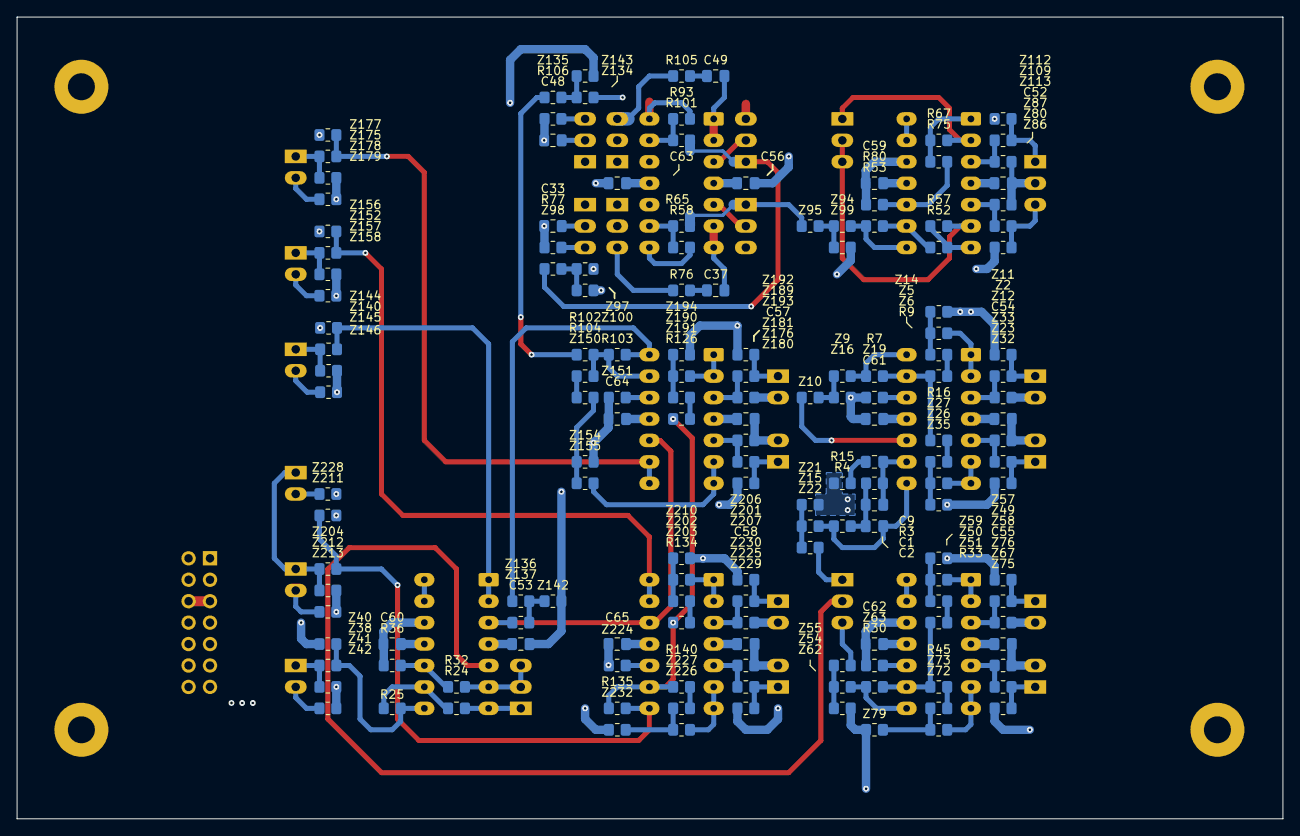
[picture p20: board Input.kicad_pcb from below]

Board: 4 copper layers, 150.0 x 95.0 mm, 190 parts (155 on the bottom side), 126 nets.

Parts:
C1: 2n2; C_0805_2012Metric_Pad1.18x1.45mm_HandSolder
C2: 10n; C_0805_2012Metric_Pad1.18x1.45mm_HandSolder
C3: 10n; C_1210_3225Metric_Pad1.33x2.70mm_HandSolder
C9: 47u; C_0805_2012Metric_Pad1.18x1.45mm_HandSolder
C33, C48: 470p; C_0805_2012Metric_Pad1.18x1.45mm_HandSolder
C37, C49: 3n; C_0805_2012Metric_Pad1.18x1.45mm_HandSolder
C52, C53, C54, C55, C56, C57, C58, C59, C60, C61, C62, C63, C64, C65: 100n; C_0805_2012Metric_Pad1.18x1.45mm_HandSolder
H1, H6, H7: MountingHole; MountingHole_3.2mm_M3_Pad
H3: MountingHole_Pad; MountingHole_3.2mm_M3_Pad
J2: R_Phono_In; PinHeader_1x02_P2.54mm_Vertical_LongPads
J3: L_Phono_In; PinHeader_1x02_P2.54mm_Vertical_LongPads
J4: Phono/Line_Out; PinSocket_1x02_P2.54mm_Vertical_LongPads
J7: R_Line_In; PinHeader_1x02_P2.54mm_Vertical_LongPads
J8: L_Line_In; PinHeader_1x02_P2.54mm_Vertical_LongPads
J9: Mic_In; PinHeader_1x03_P2.54mm_Vertical_LongPads
J12, J14, J16, J23, J27: Mic_Effekt_Out; PinSocket_1x02_P2.54mm_Vertical_LongPads
J17: AUX_RET_1; PinHeader_1x02_P2.54mm_Vertical_LongPads
J20: Effekt_In; PinHeader_1x02_P2.54mm_Vertical_LongPads
J22: AUX_RET_2; PinHeader_1x02_P2.54mm_Vertical_LongPads
J28: AUX_RET_3; PinHeader_1x02_P2.54mm_Vertical_LongPads
J30: Conn_02x07_Odd_Even; PinHeader_2x07_P2.54mm_Vertical
R3: 36k; R_0805_2012Metric_Pad1.20x1.40mm_HandSolder
R4: 390k; R_0805_2012Metric_Pad1.20x1.40mm_HandSolder
R7, R9, R16, R25, R30, R33, R45, R52, R53, R57, R67, R75, R80, R102, R103, R104, R126, R134, R135, R140: 10k; R_0805_2012Metric_Pad1.20x1.40mm_HandSolder
R15, R36: 1k; R_0805_2012Metric_Pad1.20x1.40mm_HandSolder
R24: 4k7; R_0805_2012Metric_Pad1.20x1.40mm_HandSolder
R32: 470R; R_0805_2012Metric_Pad1.20x1.40mm_HandSolder
R58, R65, R93, R101: 22k; R_0805_2012Metric_Pad1.20x1.40mm_HandSolder
R76, R77, R105, R106: 6k8; R_0805_2012Metric_Pad1.20x1.40mm_HandSolder
RV4: 50k log; PinSocket_1x03_P2.54mm_Vertical_LongPads
RV9: 10k lin; PinSocket_1x03_P2.54mm_Vertical_LongPads
RV11: 220k log; PinSocket_2x03_P2.54mm_Vertical_LongPads
RV13, RV18: 47k lin; PinSocket_1x03_P2.54mm_Vertical_LongPads
RV17: 220k log; PinSocket_2x03_P2.54mm_Vertical_LongPads_Mirrored
SW2: SW_SPDT; PinHeader_1x03_P2.54mm_Vertical_LongPads
U4, U8, U9, U11, U15, U17, U19: TL074; DIP-14_W7.62mm_Socket_LongPads
Z2, Z5, Z6, Z9, Z10, Z11, Z12, Z14, Z15, Z16, Z19, Z21, Z22, Z23, Z26, Z27, Z32, Z33, Z35, Z38, Z40, Z41, Z42, Z49, Z50, Z51, Z54, Z55, Z57, Z58, Z59, Z62, Z63, Z67, Z72, Z73, Z75, Z76, Z79, Z80, Z86, Z87, Z94, Z95, Z97, Z98, Z99, Z100, Z109, Z112, Z113, Z134, Z135, Z136, Z137, Z140, Z142, Z143, Z144, Z145, Z146, Z150, Z151, Z152, Z154, Z155, Z156, Z157, Z158, Z175, Z176, Z177, Z178, Z179, Z180, Z181, Z189, Z190, Z191, Z192, Z193, Z194, Z201, Z202, Z203, Z204, Z206, Z207, Z210, Z211, Z212, Z213, Z224, Z225, Z226, Z227, Z228, Z229, Z230, Z232: R_0805_2012Metric_Pad1.20x1.40mm_HandSolder

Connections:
9V_GND_I: J30.1, J30.2, J30.3, J30.4
+9V_I: J30.5, J30.6
+15V_I: C52.1, C53.2, C54.2, C55.2, C56.2, C57.2, C58.2, J30.13, J30.14, U4.4 (V+), U8.4 (V+), U9.4 (V+), U11.4 (V+), U15.4 (V+), U17.4 (V+), U19.4 (V+)
-15V_I: C59.2, C60.2, C61.2, C62.2, C63.2, C64.2, C65.2, J30.7, J30.8, U4.11 (V-), U8.11 (V-), U9.11 (V-), U11.11 (V-), U15.11 (V-), U17.11 (V-), U19.11 (V-)
GND_I: C3.2, C33.2, C48.2, C52.2, C53.1, C54.1, C55.1, C56.1, C57.1, C58.1, C59.1, C60.1, C61.1, C62.1, C63.1, C64.1, C65.1, J2.2, J3.2, J7.2, J8.2, J9.2, J17.2, J20.2, J22.2, J28.2, J30.9, J30.10, J30.11, J30.12, R15.1, R36.1, R77.1, R80.1, R106.1, U8.12 (+), U9.12 (+), U11.12 (+), Z11.2, Z12.2, Z14.2, Z16.2, Z19.2, Z21.2, Z32.2, Z33.2, Z35.2, Z40.2, Z41.2, Z42.2, Z57.2, Z58.2, Z59.2, Z62.2, Z63.2, Z75.2, Z76.2, Z79.2, Z86.2, Z87.2, Z99.2, Z100.2, Z112.2, Z113.2, Z142.2, Z143.1, Z144.2, Z145.2, Z146.2, Z151.2, Z154.2, Z156.2, Z157.2, Z158.2, Z177.2, Z178.2, Z179.2, Z180.2, Z181.2, Z192.2, Z193.2, Z194.2, Z206.2, Z207.2, Z210.2, Z211.2, Z212.2, Z213.2, Z224.2, Z228.2, Z229.2, Z230.2, Z232.2
unnamed: C1.2, C2.1, R3.1, R4.2
unnamed: C2.2, R4.1, U4.8, Z15.1
unnamed: C3.1, H3.1
unnamed: C9.1, R15.2
unnamed: C37.1, R76.1
unnamed: C49.1, R105.1
unnamed: J2.1, Z2.1, Z11.1
unnamed: J3.1, Z23.1, Z32.1
unnamed: J4.1, Z38.2, Z41.1
unnamed: J4.2, Z42.1
unnamed: J7.1, Z49.1, Z57.1
unnamed: J8.1, Z67.1, Z75.1
unnamed: J9.1, Z109.1, Z112.1
unnamed: J9.3, Z80.1, Z86.1
unnamed: J12.1, Z140.2, Z145.1
unnamed: J12.2, Z146.1
unnamed: J14.1, Z152.2, Z157.1
unnamed: J14.2, Z158.1
unnamed: J16.1, Z175.2, Z178.1
unnamed: J16.2, Z179.1
unnamed: J17.1, Z176.1, Z180.1
unnamed: J20.1, Z189.1, Z192.1
unnamed: J22.1, Z201.1, Z206.1
unnamed: J23.1, J27.1, Z204.2, Z212.1
unnamed: J23.2, Z213.1
unnamed: J27.2, Z228.1
unnamed: J28.1, Z225.1, Z229.1
unnamed: R7.2, U4.14, Z9.1
unnamed: R9.1, Z6.2
unnamed: R16.1, Z27.2
unnamed: R24.1, RV4.1, U8.7
unnamed: R25.2, U8.8, Z38.1, Z40.1
unnamed: R30.2, U9.8, Z54.1
unnamed: R33.1, Z51.2
unnamed: R45.1, Z73.2
unnamed: R52.1, R57.2, U11.7
unnamed: R53.1, U11.8, Z94.1
unnamed: R58.2, RV13.3, U15.8, Z97.1
unnamed: R65.1, RV13.1, Z95.2
unnamed: R67.1, R75.1, U11.1
unnamed: R76.2, RV11.3
unnamed: R77.2, RV11.4
unnamed: R93.2, RV18.3, U15.14, Z134.1
unnamed: R101.1, RV18.1, Z98.2
unnamed: R102.1, Z135.2
unnamed: R103.2, U17.14, Z136.1
unnamed: R104.1, Z150.1
unnamed: R105.2, RV17.3
unnamed: R106.2, RV17.4
unnamed: R126.2, Z191.2
unnamed: R134.2, Z203.2
unnamed: R135.1, U19.8, Z204.1, Z211.1
unnamed: R140.2, Z227.2
unnamed: SW2.1 (A), Z22.2
unnamed: SW2.2 (B), U8.5 (+)
unnamed: SW2.3 (C), Z55.2
unnamed: U4.3 (+), Z2.2, Z12.1
unnamed: U4.1, U4.2 (-), Z5.1
unnamed: U4.5 (+), Z23.2, Z33.1
unnamed: U4.6 (-), U4.7, Z26.1
unnamed: U4.10 (+), Z10.2
unnamed: C1.1, C9.2, R3.2, U4.9 (-)
unnamed: U4.12 (+), Z19.1
unnamed: R7.1, R9.2, R16.2, U4.13 (-)
unnamed: U8.1, U8.2 (-), Z140.1, Z144.1
unnamed: R32.1, RV4.2, RV4.3, U8.6 (-)
unnamed: R32.2, R36.2, U8.10 (+)
unnamed: R24.2, R25.1, U8.9 (-)
unnamed: U8.13 (-), U8.14
unnamed: U9.3 (+), Z49.2, Z58.1
unnamed: U9.1, U9.2 (-), Z50.1
unnamed: U9.5 (+), Z67.2, Z76.1
unnamed: U9.6 (-), U9.7, Z72.1
unnamed: U9.10 (+), Z63.1
unnamed: R30.1, R33.2, R45.2, U9.9 (-)
unnamed: U9.13 (-), U9.14
unnamed: U11.3 (+), Z109.2, Z113.1
unnamed: R67.2, RV9.1, U11.2 (-)
unnamed: U11.5 (+), Z80.2, Z87.1
unnamed: R57.1, RV9.2, RV9.3, U11.6 (-)
unnamed: R75.2, R80.2, U11.10 (+)
unnamed: R52.2, R53.2, U11.9 (-)
unnamed: U11.13 (-), U11.14
unnamed: RV18.2, U15.3 (+)
unnamed: C49.2, U15.1, U15.2 (-)
unnamed: RV13.2, U15.5 (+)
unnamed: C37.2, U15.6 (-), U15.7
unnamed: C33.1, RV11.1, RV11.2, RV11.5, RV11.6, U15.10 (+)
unnamed: R58.1, R65.2, U15.9 (-)
unnamed: C48.1, RV17.1, RV17.2, RV17.5, RV17.6, U15.12 (+)
unnamed: R93.1, R101.2, U15.13 (-)
unnamed: U17.3 (+), Z189.2, Z193.1
unnamed: U17.1, U17.2 (-), Z190.1
unnamed: U17.5 (+), Z176.2, Z181.1
unnamed: U17.6 (-), U17.7, Z155.2
unnamed: U8.3 (+), U17.10 (+), U19.12 (+), Z137.2
unnamed: U17.8, U17.9 (-), Z175.1, Z177.1
unnamed: U17.12 (+), Z151.1
unnamed: R102.2, R103.1, R104.2, U17.13 (-)
unnamed: U19.3 (+), Z201.2, Z207.1
unnamed: U19.1, U19.2 (-), Z202.1
unnamed: U19.5 (+), Z225.2, Z230.1
unnamed: U19.6 (-), U19.7, Z226.1
unnamed: U19.10 (+), Z224.1
unnamed: R126.1, R134.1, R135.2, R140.1, U19.9 (-)
unnamed: U19.13 (-), U19.14, Z152.1, Z156.1
unnamed: Z9.2, Z10.1, Z16.1
unnamed: Z5.2, Z6.1, Z14.1
unnamed: Z15.2, Z21.1, Z22.1
unnamed: Z26.2, Z27.1, Z35.1
unnamed: Z50.2, Z51.1, Z59.1
unnamed: Z54.2, Z55.1, Z62.1
unnamed: Z72.2, Z73.1, Z79.1
unnamed: Z94.2, Z95.1, Z99.1
unnamed: Z97.2, Z98.1, Z100.1
unnamed: Z134.2, Z135.1, Z143.2
unnamed: Z136.2, Z137.1, Z142.1
unnamed: Z150.2, Z154.1, Z155.1
unnamed: Z190.2, Z191.1, Z194.1
unnamed: Z202.2, Z203.1, Z210.1
unnamed: Z226.2, Z227.1, Z232.1

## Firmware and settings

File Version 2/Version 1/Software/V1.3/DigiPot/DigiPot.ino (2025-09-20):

#include <SPI.h>

#define WRITE_CMD 0x00


const int numEntries = 96;  // Maximale Anzahl der Einträge, die pro Block eingelesen werden

// Struktur für die gespeicherten Daten
struct DataEntry {
  int csPin;
  long address;
  int associatedValue;
};

// Array, das die empfangenen Daten speichert
DataEntry dataEntries[numEntries];

void setPotiValue(int csPin, long address, int value) {
  byte commandByte = (address << 4) | WRITE_CMD;  // WRITE_CMD ist 0x00
  byte dataByte = value;  

  pinMode(csPin, OUTPUT);  // Chip-Select als Ausgang definieren

  digitalWrite(csPin, LOW);  // Chip-Select aktivieren (LOW)
  digitalWrite(csPin, LOW);  // Chip-Select aktivieren (LOW)
  SPI.transfer(commandByte);  // Befehl senden
  SPI.transfer(dataByte);  // Wert senden
  digitalWrite(csPin, HIGH);  // Chip-Select deaktivieren (HIGH)
}

void setup() {

  Serial.begin(9600);  // Seriellen Monitor starten
  SPI.begin();  // SPI starten
  SPI.beginTransaction(SPISettings(100000, MSBFIRST, SPI_MODE0));
  
}

void loop() {
  int index = 0;

  // Wir lesen Zeile für Zeile und speichern die Daten
  while (Serial.available() > 0 && index < numEntries) {
    String data = Serial.readStringUntil('\n');  // Daten bis zum nächsten Zeilenumbruch lesen

    if (data.length() > 0) {
      int firstCommaIndex = data.indexOf(',');
      String chipSelect = data.substring(0, firstCommaIndex);
      dataEntries[index].csPin = chipSelect.toInt();

      String restOfData = data.substring(firstCommaIndex + 1);
      int secondCommaIndex = restOfData.indexOf(',');

      String adress = restOfData.substring(0, secondCommaIndex);
      dataEntries[index].address = adress.toInt(); 

      String associatedValue = restOfData.substring(secondCommaIndex + 1);
      dataEntries[index].associatedValue = associatedValue.toInt();

      index++;  // Zum nächsten Eintrag weitergehen
    }
  }
  // Verarbeite die gespeicherten Daten und sende sie an das Digipot
  for (int i = 0; i < index; i++) {
    setPotiValue(dataEntries[i].csPin, dataEntries[i].address, dataEntries[i].associatedValue);
  }

  //delay(10);  // Kleine Pause zwischen den Blöcken (optional)
}

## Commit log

2025-11-10 Einpflegen der Eingangsstufe
    [DiKo_PreAmp.kicad_sch]
2025-11-20 Eingangsstufe update
    [DiKo_PreAmp.kicad_sch]
2025-11-24 Schaltplan Update
    [DiKo_PreAmp.kicad_sch]
2025-12-16 Schaltplan und Blockschaltbild Update
    [DiKo_PreAmp.kicad_sch]
2025-12-20 Footprint Update
    [DiKo_PreAmp.kicad_sch]
2025-12-22 PCB Update
    [Input.kicad_pcb, Input.kicad_sch]
2026-01-01 PCB Update Power Supply VU Amp
    [Input.kicad_pcb, Power_Supply_Meter_Amp.kicad_pcb, Power_Supply_Meter_Amp.kicad_sch]
2026-02-16 PCB Final Update
    [Input.kicad_pcb, Input.kicad_sch, Output.kicad_pcb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]
2026-02-19 common mode chocke Update
    [Power_Supply_Meter_Amp.kicad_pcb]
2026-02-24 final PCB Update
    [DiKo_PreAmp.kicad_sch, Input.kicad_pcb, Input.kicad_sch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]
2026-03-05 Output phasen korrektur durch invertierender verstärker
    [Output.kicad_pcb, Output.kicad_sch, Power_Supply_Meter_Amp.kicad_pcb]
2026-03-09 Output Stage in phase gebracht
    [Output.kicad_pcb, Output.kicad_sch]
2026-03-16 DRC Update
    [100SP1T1B4M2QE.SchLib, 61300211121.SchLib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]
2026-03-16 Gerber Update
    [Input-B_Mask.gbs, Input-B_Paste.gbp, Input-B_Silkscreen.gbo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]
2026-03-22 Bezeichner und BOM Update
    [DiKo_PreAmp.csv, DiKo_PreAmp.kicad_sch, Elektrometersubtrahierer.kicad_pcb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]
2026-04-02 Kicad Einstellungen
2026-04-03 Einganststufe Update
    [DiKo_PreAmp.kicad_sch, Power_Supply_Meter_Amp.kicad_pcb]
2026-04-14 RIAA Spice
    [RIAA.kicad_sch, Spannungsteiler.kicad_sch]
2026-04-19 phono aktulisert
    [DiKo_PreAmp.kicad_sch]
2026-05-03 EQ Output Update
    [DiKo_PreAmp.kicad_sch, HP_Tubby.kicad_sch, Optimaler_Amp.kicad_sch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]
2026-05-06 Update Outputstage
    [DiKo_PreAmp.kicad_sch, HP_Tubby.kicad_sch]
2026-05-10 Update mit Fotos und Blockschaltbild
    [100SP1T1B4M2QE.SchLib, 61300211121.SchLib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]
2026-05-11 Bass Bandpass Update
    [DiKo_PreAmp.kicad_sch]
2026-05-12 update kick
    [DiKo_PreAmp.kicad_sch]
2026-05-13 Mitten Update
    [DiKo_PreAmp.kicad_sch]
2026-05-15 Höhen Update
    [Bandpass.kicad_sch, DiKo_PreAmp.kicad_sch]
2026-05-15 Finales Update Ausgangsstufe
    [DiKo_PreAmp.kicad_sch, Optimaler_Amp.kicad_sch]
2026-05-16 Pegel Update
    [DiKo_PreAmp.kicad_sch, Pegelanzeige.kicad_sch]
2026-05-16 VU Test
    [DiKo_PreAmp.kicad_sch, Pegelanzeige.kicad_sch]
2026-05-17 VU Update
    [DiKo_PreAmp.kicad_sch, Pegelanzeige.kicad_sch, Spannungsteiler.kicad_sch]
2026-06-02 Erste mal musik durch geschickt
    [DiKo_PreAmp.kicad_sch, Elektrometersubtrahierer.kicad_sch]
2026-10-05 Version 3
    [100SP1T1B4M2QE.SchLib, 61300211121.SchLib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]
